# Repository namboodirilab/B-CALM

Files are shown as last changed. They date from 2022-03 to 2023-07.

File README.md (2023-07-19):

# Behavior Controller for Associative Learning and Memory (B-CALM): Software and Hardware Introduction 
This readme file briefly introduces the supplementary files for the Behavior controller system for assoctiative learning and memory (B-CALM). You can access the paper for free [here](https://rdcu.be/dha7x) <br />
 <br />

### [CIRCUIT SCHEMATIC PDF FILE](https://github.com/namboodirilab/B-CALM/blob/main/circuit%20schematic.pdf)
- This file contains the circuit schematic, building instructions and parts purchase list for our electronic system used in B-CALM.  <br />

### [TASK RUNNING OVERVIEW PDF FILE](https://github.com/namboodirilab/B-CALM/blob/main/Task%20running%20overview.pdf)
- This file contains the **MATLAB code and GUI setup instructions**, **task running instructions**, **the graphical user interface (GUI) parameters full explanation**, and **possible future tasks and parameter setting explanation**.   <br />

### [TASK CODES FOLDER](https://github.com/namboodirilab/B-CALM/tree/main/task%20codes)
 The first part of this folder contains the **MATLAB GUI code**--[headfix_GUI.m](https://github.com/namboodirilab/B-CALM/blob/main/task%20codes/headfix_GUI.m), **the actual GUI figure file made in GUIDE**--[headfix_GUI.fig](https://github.com/namboodirilab/B-CALM/blob/main/task%20codes/headfix_GUI.fig),  and **the data saving and plotting file** for current experiment--[conditioning_prog.m](https://github.com/namboodirilab/B-CALM/blob/main/task%20codes/conditioning_prog.m).
  
  We have also developed a programmatic GUI, running code with the plotting function in the [programmatic GUI folder](https://github.com/namboodirilab/B-CALM/tree/main/task%20codes/programmatic%20GUI) to adapt to MATLAB's future versions which will discontinue GUIDE. 

  The second part of this folder contains five Arduino task scripts for running five different experiments. Task parameters and instructions of running each one are documented in the [Task running overview](https://github.com/namboodirilab/B-CALM/blob/main/Task%20running%20overview.pdf). <br />
  - [Namlab_behavior_cues.ino](https://github.com/namboodirilab/B-CALM/tree/main/task%20codes/Namlab_behavior_cues) - This is experiment mode one in the GUI setting. This is for cue triggered experiments (both Pavlovian and cue-action-reward). <br />
  - [Namlab_behavior_randomrewards.ino](https://github.com/namboodirilab/B-CALM/tree/main/task%20codes/Namlab_behavior_randomrewards) - This is experiment mode two in the GUI, for lick training animals with a poission distribution of rewards. <br />
  - [Namlab_behavior_lickforreward.ino](https://github.com/namboodirilab/B-CALM/tree/main/task%20codes/Namlab_behavior_lickforreward) - This is experiment mode three in the GUI, for operant/instrumental action-reward associated tasks. <br />
  - [Namlab_behavior_decisionmaking.ino](https://github.com/namboodirilab/B-CALM/tree/main/task%20codes/Namlab_behavior_decisionmaking) - This is experiment mode four in the GUI, mainly for decision making tasks with the possible implentation of different cues, reward magnitudes, and delays for either choices. <br />
  - [Namlab_behavior_ramptiming.ino](https://github.com/namboodirilab/B-CALM/tree/main/task%20codes/Namlab_behavior_ramptiming) - This is experiment mode six in the GUI, for studying a ramp timing task with reward magnitude varying based on the ramp (not part of the B-CALM paper). <br />
  
  (These five experiments include nearly all possible task combinations and setups for running common associative learning and memory tasks. Other experiment mode task files beyond the scope of the paper are not included here currently since they are being validated. <br />
  
### [DATA ANALYSIS CODES FOLDER](https://github.com/namboodirilab/B-CALM/tree/main/data%20analysis%20codes)  <br />
  This folder contains five MATLAB data analysis codes for analyzing the five different tasks we've demonstrated in the paper. All analysis codes are documented to guide users to understand the logic behind our analysis. 
  - [cueactionrewardtask.m](https://github.com/namboodirilab/B-CALM/blob/main/data%20analysis%20codes/cueactionrewardtask.m) - This file is for analyzing and plotting the Cue-action-reward task in the paper. <br />
  - [desisionmakingtask.m](https://github.com/namboodirilab/B-CALM/blob/main/data%20analysis%20codes/decisionmakingtask.m) - This file is for analyzing the decision-making task in the paper. <br />
  - [operanttask.m](https://github.com/namboodirilab/B-CALM/blob/main/data%20analysis%20codes/operanttask.m) This is for analyzing the operant conditioning task demonstrated in the paper. <br />
  - [pavloviantask.m](https://github.com/namboodirilab/B-CALM/blob/main/data%20analysis%20codes/pavloviantask.m) - This file is for analyzing the Pavlovian conditioning file shown in the paper. <br />
  - [timingtask.m](https://github.com/namboodirilab/B-CALM/blob/main/data%20analysis%20codes/timingtaskraster.m) - This file is for analyzing the interval timing task demonstrated in the paper. <br />
  
### [HEAD_FIXED_SETUP FOLDER](https://github.com/namboodirilab/B-CALM/tree/main/head_fixed_setup)  <br />
  This folder contains:
  - [head_fixed stage setup overview](https://github.com/namboodirilab/B-CALM/blob/main/head_fixed_setup/Head-fixed%20stage%20setup%20overview.pdf) - this file explains the instructions for building our current head_fixed stage and the reward delivery system. It also contains the overview pictures for our 3D printing parts, lick tube positioning instructions and the head-fixed stage parts purchase information index.
  - [CAD files folder](https://github.com/namboodirilab/B-CALM/tree/main/head_fixed_setup/CAD%20files) - this folder contains the [head-fixed stage base design](https://github.com/namboodirilab/B-CALM/blob/main/head_fixed_setup/CAD%20files/base%20design%20clean.step), the [head-fixed holder top piece](https://github.com/namboodirilab/B-CALM/blob/main/head_fixed_setup/CAD%20files/Original_holdertop.SLDPRT), and the [head-fixed holder bottom piece](https://github.com/namboodirilab/B-CALM/blob/main/head_fixed_setup/CAD%20files/Original_holderbottom_mod.SLDPRT). All three items were custom made through [eMachineShop](https://www.emachineshop.com/main/). (Orders require submiting quotes with those CAD files through the eMachineShop website. Please note that this is not to endorse eMachineShop. Any machine shop should be able to make these parts)
  - [3D printing files](https://github.com/namboodirilab/B-CALM/tree/main/head_fixed_setup/3D%20printing%20files) - this folder contains all the 3D printing files we utilized in the head-fixed stage setup.
    - [Final_2_lick_tube_holder_levelholes.stl](https://github.com/namboodirilab/B-CALM/blob/main/head_fixed_setup/3D%20printing%20files/Final_2_lick_tube_holder_levelholes.stl) - this is the middle two lick tube holder piece.
    - [Final_retraction_solenoid_wing_holder.stl](https://github.com/namboodirilab/B-CALM/blob/main/head_fixed_setup/3D%20printing%20files/Final_retraction_solenoid_wing_holder.stl) - this is the two retraction solenoid wing holder.
    - [Final_left_retraction_solenoid_attachment.stl](https://github.com/namboodirilab/B-CALM/blob/main/head_fixed_setup/3D%20printing%20files/Final_left_retraction_solenoid_attachment.stl) - this is the left side retraction solenoid attachment piece. Left is relative to the mouse snout. 
    - [Final_right_retraction_solenoid_attachment_30mm.stl](https://github.com/namboodirilab/B-CALM/blob/main/head_fixed_setup/3D%20printing%20files/Final_right_retraction_solenoid_attachment_30mm.stl) - this is the right side retraction solenoid attachment piece.

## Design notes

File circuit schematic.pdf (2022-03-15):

Circuit Schematic, building instructions, and parts list

Here, we show the circuit schematic. We first discuss why we chose to use breadboards as our permanent circuits instead of printed circuit boards (PCBs) before explaining how to wire the circuit and how the circuit operates.

PCB vs breadboards:

Our primary design goal for the circuit was for it to be stable, yet flexible enough that hardware components can be easily added, removed, or replaced. For this reason, we decided to build a permanent solution using breadboards. The choice of breadboards for a permanent circuit may be non-intuitive. Hence, we explain this choice here.

1. PCBs are fantastic when a circuit is fully stable and no change in hardware configuration will be necessary in the future. However, when the hardware configuration changes, a PCB needs to be redesigned, which requires time, effort, and money. Since we would like the hardware in our system to be quickly modifiable, we resort to using breadboards, wherein changes are easy to make.
2. Though circuits on breadboards can be unstable when assembled with poor quality boards, or with inappropriate wires, they can be highly stable when made appropriately (good quality boards, solid core wires and leads with appropriate thickness).
3. When circuit components fail, they can be quickly replaced from a breadboard. This is much harder with fully assembled PCBs, especially those with built-in small form factor chips.
4. Making this circuit on a breadboard allows other labs to potentially modify the circuit to add their own hardware. A fully assembled PCB would not easily allow such modification.
5. Despite these advantages, breadboards have a major disadvantage due to stray capacitances. These capacitances slow signal processing and this is a major reason why breadboards are not used for applications requiring sub-microsecond clocking. However, for controlling animal behavior, the highest signal frequencies of interest are only over millisecond timescales. Thus, in this frequency space, breadboards are fully functional. Indeed, one can make a functional computer on breadboards despite the constraints on processing speed (https://eater.net/8bit/)

How this circuit works:

The general principle of design for this circuit is simple. For any hardware component, we allocate one of the IO pins on the Arduino Mega as an input or an output. Since in our case, all such connections are digital, we use the digital pins of the Arduino Mega. In our case, the inputs are lick measurements for the three lick tubes (left, right and center). The outputs are one to four fluid delivery solenoids, two lick tube retraction solenoids, two buzzers, and two LEDs. The fluid delivery solenoids can be hooked up to the three lick tubes, with one each for the left and right tube and two for the two separate electrically connected tubes in the center lick tube. In practice, for most simple experiments, one would only need a single fluid delivery solenoid for one of the center tubes. In the behavioral tasks shown in Zhou et al., we use only one fluid delivery solenoid to deliver sucrose, except for the experiment in which quinine is also delivered (two total fluid delivery solenoids in this case). Each of these connection types (lick detection, buzzer, LED, fluid delivery solenoid, lick tube retraction solenoid) has its own circuit motif that is repeated for the desired number of hardware components. These are described below.

Lick detection: We used a previously published circuit for detecting licks (Slotnick 2009). The only two changes we made are to add a Schmitt trigger to debounce the detected licks, and to use a 9V power supply instead of a battery.

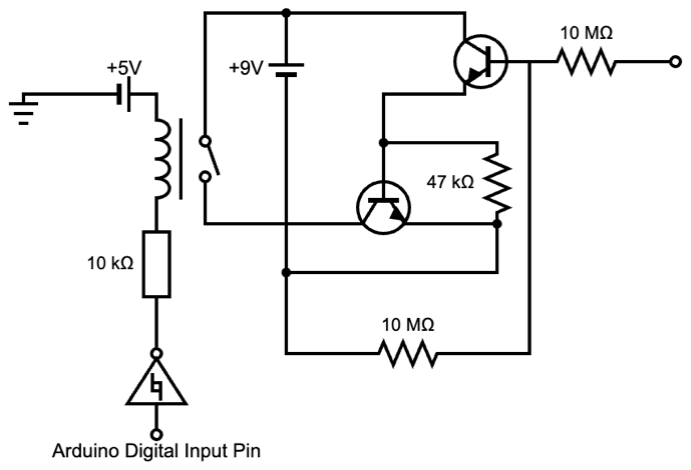
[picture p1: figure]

Buzzers and LEDs: This circuit simply connects one lead of the buzzer/LED to an Arduino digital output pin through a resistor, with the other lead connected to ground.

Fluid delivery solenoid: We used a power transistor (TIP120) as a switch to drive a 24V supply through the solenoid whenever the base of the transistor was turned to a high voltage by the Arduino output pin. Thus, the Arduino output pin was connected to the base of TIP120 through a resistor (to limit current) and the solenoid was connected on a path from a 24V supply to the collector of the TIP120. The emitter was connected to ground. In effect, this circuit operates as a switch, with the Arduino output either causing flow of current to the solenoid thereby turning it on, or preventing flow of current, thereby turning it off.

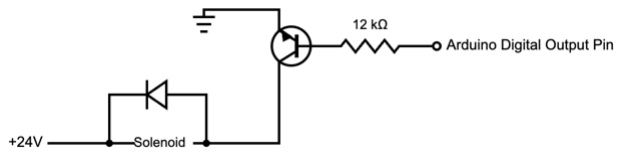
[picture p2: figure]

Lick tube retraction solenoid: This uses a similar circuit as the fluid delivery circuit, but with a MOSFET instead of TIP120. The MOSFET is more power efficient, thereby reducing any concerns of heating when the solenoid is turned on for longer durations. A MOSFET could also be used for the fluid delivery solenoid circuit.

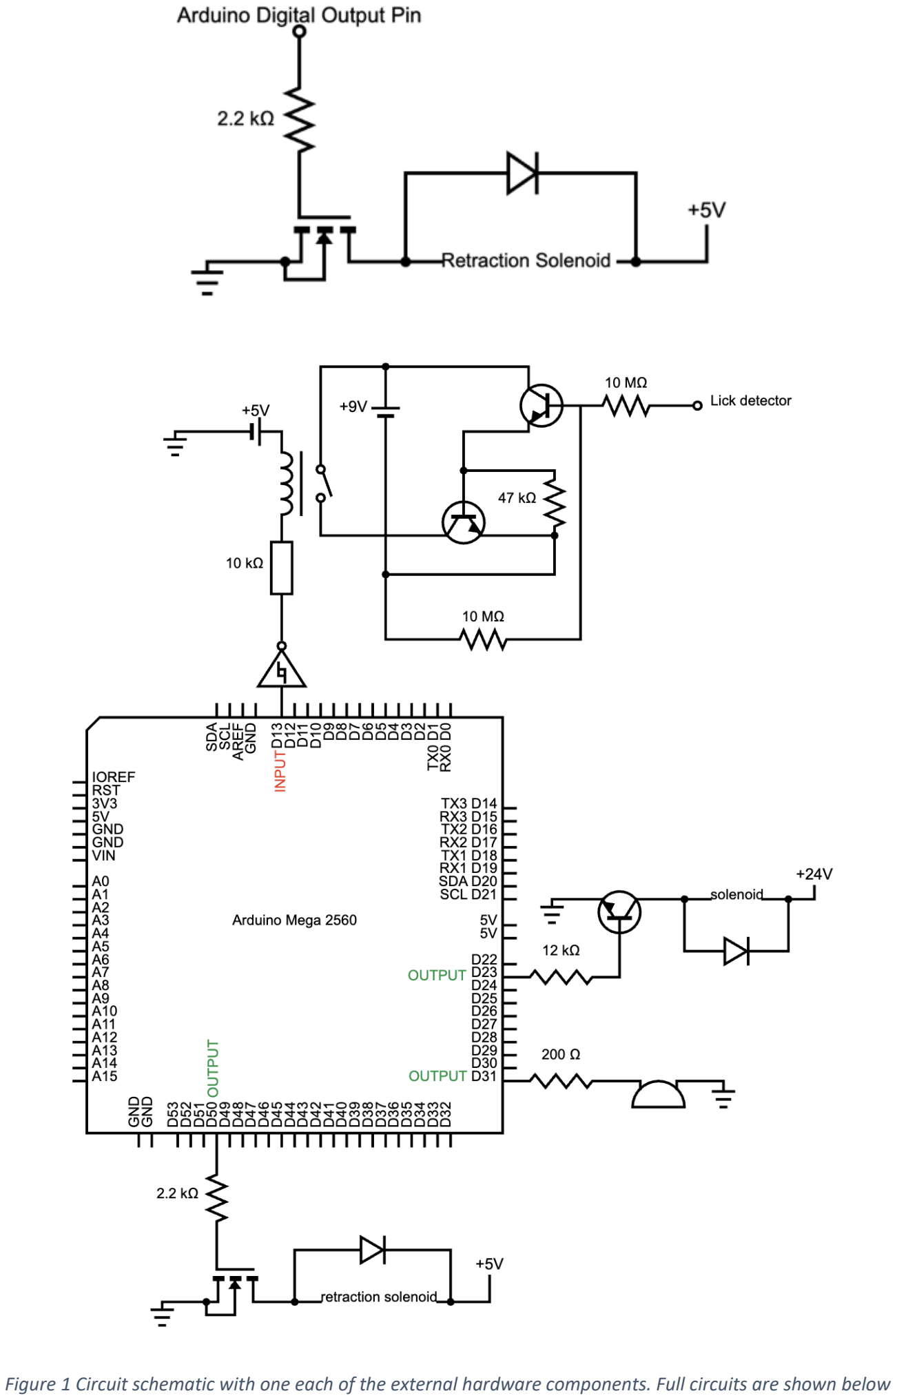
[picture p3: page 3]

Figure 1 Circuit schematic with one each of the external hardware components. Full circuits are shown below

Why we show a hand-drawn schematic (in addition to the electronically generated schematic):

Here, we show both an electronic schematic of the circuit (Fig 4) and our original hand-drawn design (Fig 2) that was used to conceptualize the circuit. The electronic circuit was designed using PICAXE Electronic Bread Board Layout Emulator (PEBBLE). We show the hand-drawn design since in personal communication with others, we have found that it provides a lower barrier to entry to understand the circuit and to make modifications. The electronic schematic provides the exact breadboard locations in which we wire our circuit and thus, can be mimicked without any understanding of the circuit function.

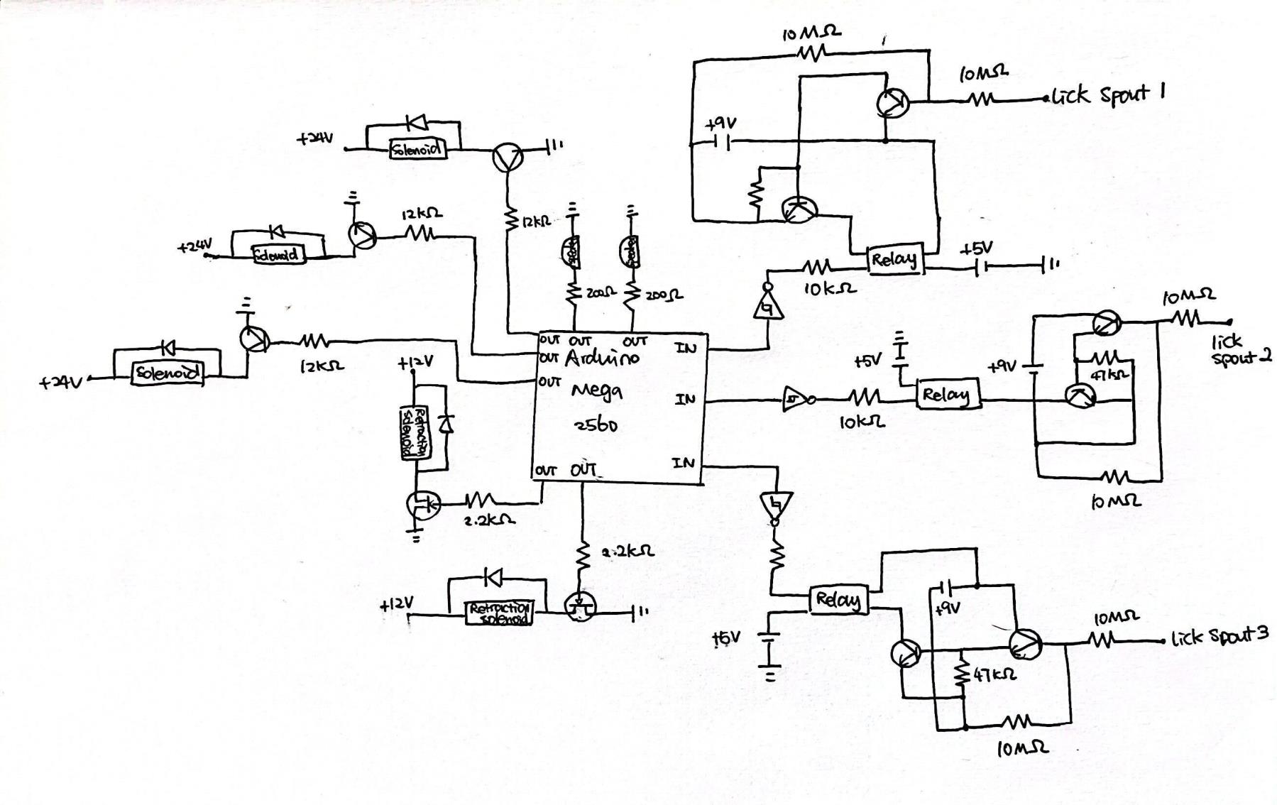
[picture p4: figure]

Figure 2 Hand-drawn full circuit schematic

Parallel running:

Our system can support multiple Arduino boards and behavioral box setups using a single computer. Separate behavioral setups are connected to the computer via USB connection. Each separate MATLAB window can control one setup and multiple setups can be executed simultaneously.

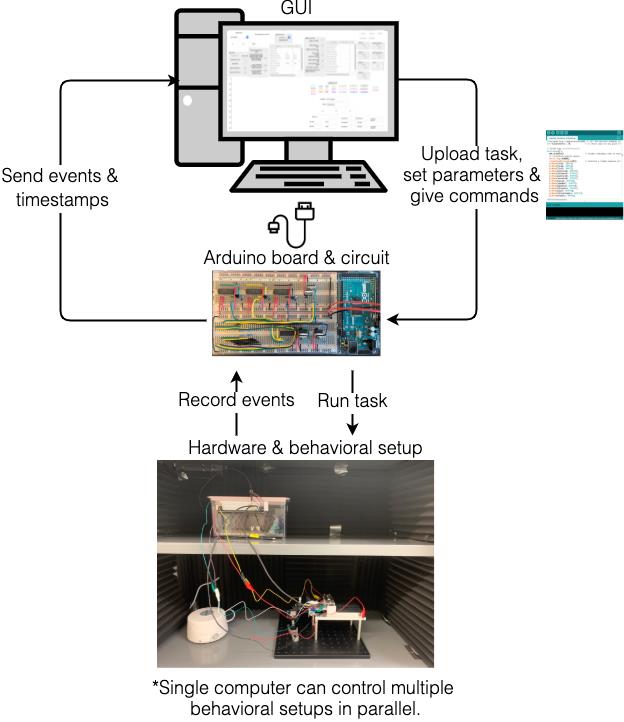
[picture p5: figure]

Building Instructions:

1. Please refer to the following photos attached for the complete circuit. All parts needed to complete the circuit is listed here. Please follow the same schematic for circuit layout.

Parts needed:

i. Lickometer systems: 10 MΩ resistors x 6, 47 kΩ resistors x 3, 10 kΩ resistors x 3, reed relay x 3, 2N222 transistor x 3, Schmitt trigger x 1, solid core wires
ii. | Linear actuator system: 2.2 kΩ resistors x 2, Power MOFSET x 2, solid core
| wires
iii. | Speakers & lights: 200 Ω resistors x 4 (speaker resistors vary, please use the
| resistor kit to test the best value)
iv. | Solenoids: 5.6 kΩ resistors x 4, TIP120 x 4, single diode x 4, solid core wire

Figure 3 System overview

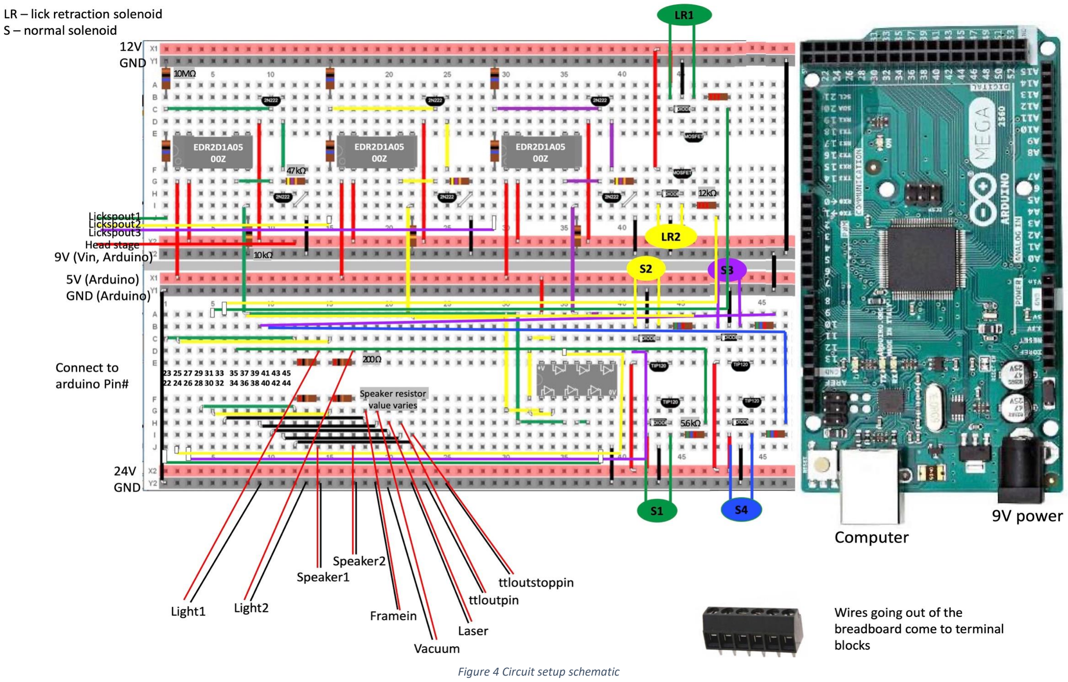
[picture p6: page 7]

Figure 4 Circuit setup schematic

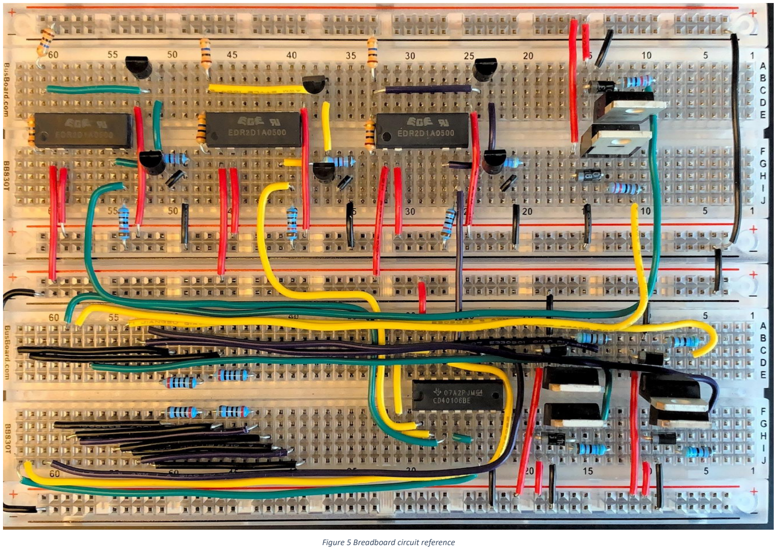
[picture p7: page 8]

Figure 5 Breadboard circuit reference

2. Dremel one rectangular opening of 15 x 0.6 cm (150 x 6 mm) on one long side (horizontal), roughly 3 cm from the top edge of the box. Dremel two square openings with length of 16 mm and 11 mm at the right bottom corner of the plastic box (Amazon 14090MDT). The distance between the two squares is around 10 mm, the distance from the bottom edge of the box to the bottom side of the squares is also around 10 mm, and the distance from the right side of the box to the right square is roughly 1.5cm. The two square openings are for putting the USB cord and 9V power to the Arduino board.

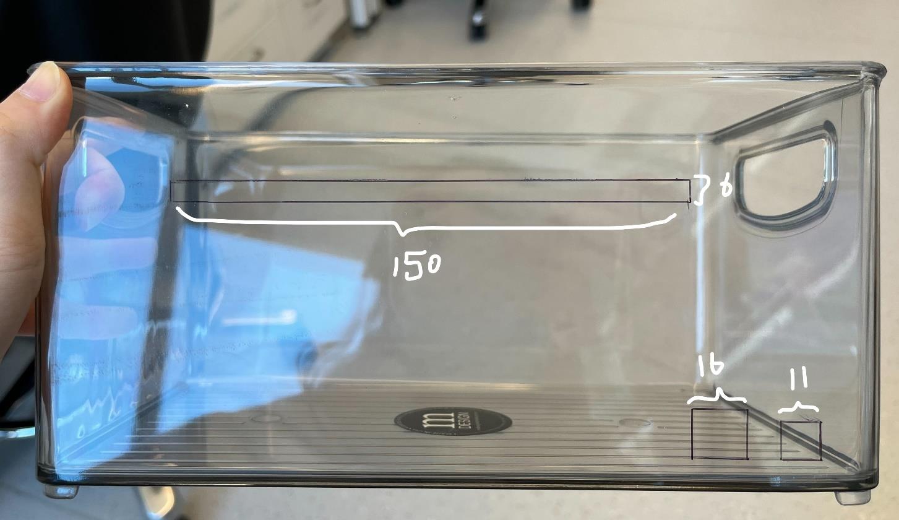
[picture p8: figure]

Figure 6 Plastic box openings size

3. Use super glue to glue 7 terminal blocks (Molex 0393570006) together. Make sure the opening slots are all facing the same way.

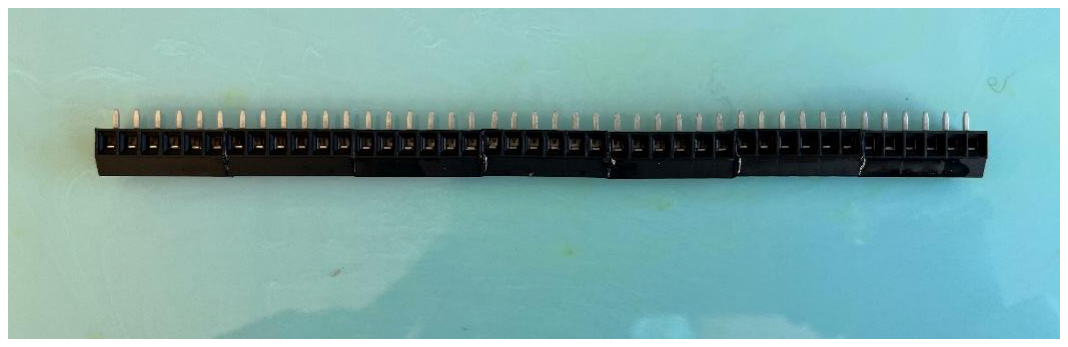
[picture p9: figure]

Figure 7 Glued terminal block

4. Place the glued terminal block into the plastic box opening with the screw slots side facing upwards. Use a hot glue gun to glue the bottom of the terminal block body onto

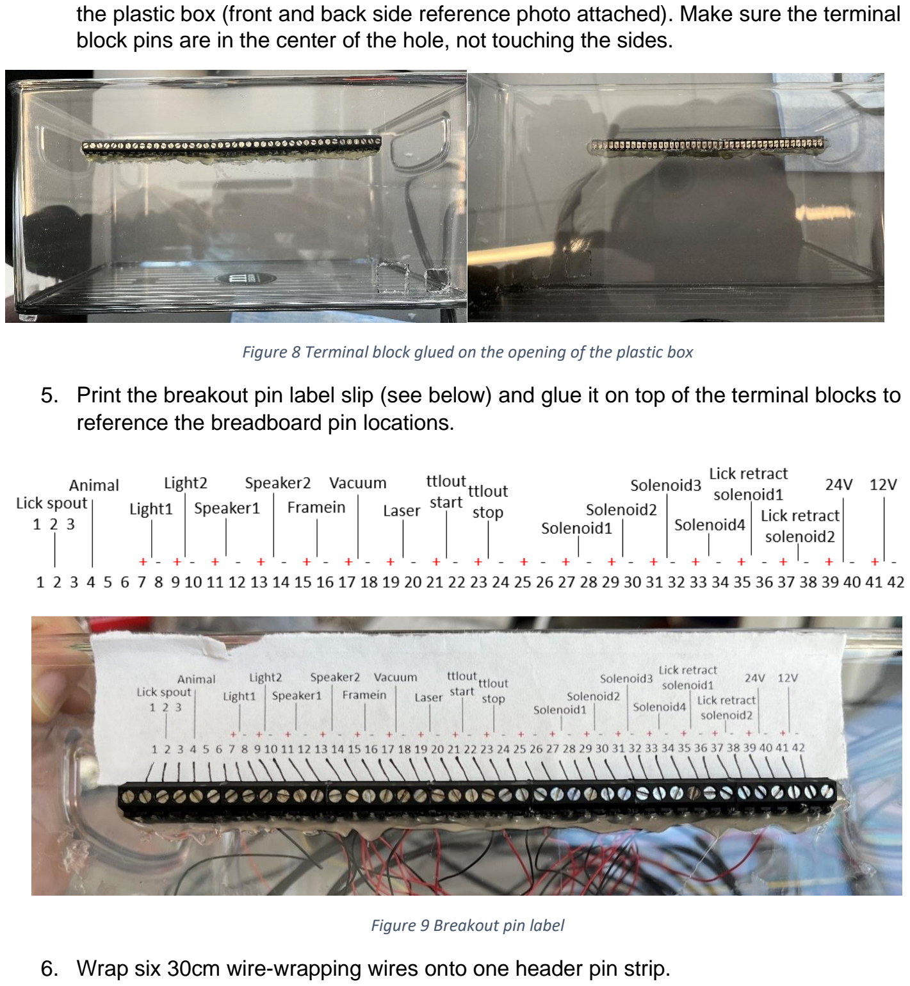
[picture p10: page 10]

the plastic box (front and back side reference photo attached). Make sure the terminal block pins are in the center of the hole, not touching the sides.

Figure 8 Terminal block glued on the opening of the plastic box

5. Print the breakout pin label slip (see below) and glue it on top of the terminal blocks to reference the breadboard pin locations.

Figure 9 Breakout pin label

6. Wrap six 30cm wire-wrapping wires onto one header pin strip.

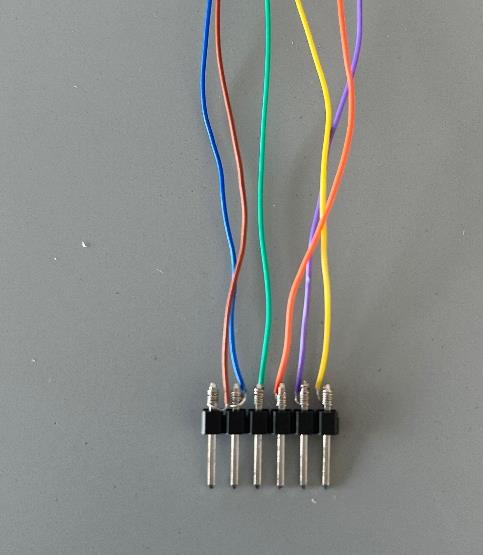
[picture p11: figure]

Figure 10 Wire wrapping on header pin strip

7. Add a heating shrink tubing to the six wires to secure them together. Leave some space on the other end to wrap the other end on another header pin strip. Make sure the order of the wires is the same for the two header pin strips (in this example: yellow→purple→orange→green→blue→brown). (This is inspired from https://hackaday.com/2019/01/06/making-your-breadboard-projects-a-little-morepermanent/).

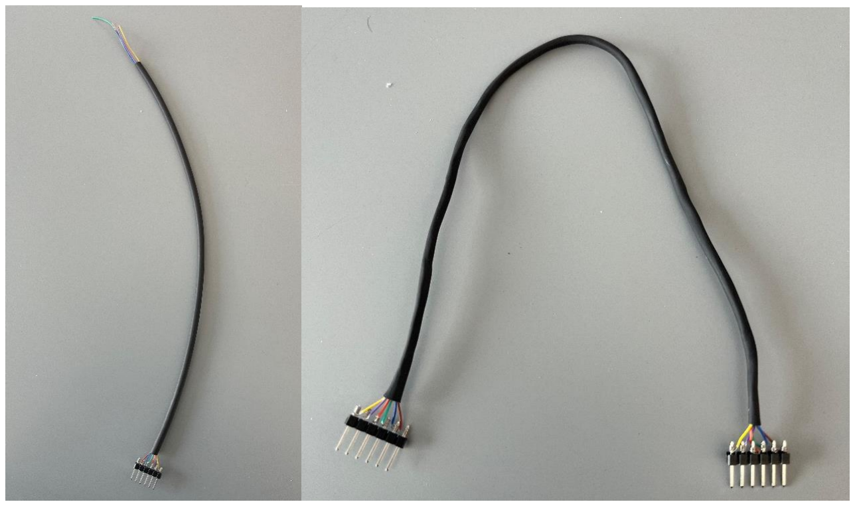
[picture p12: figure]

Figure 11 Make wire strip with two header pin strips

8. Use a hot glue gun to add a protective layer over the header pin strips. Repeat four times to make four wire strips total.

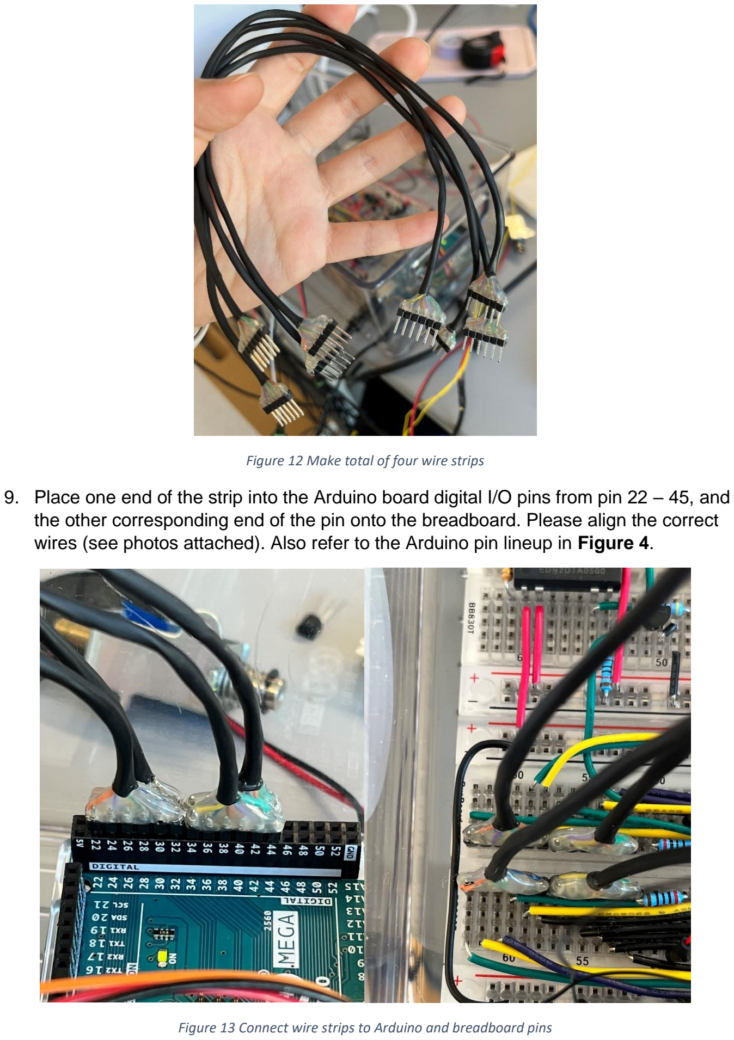
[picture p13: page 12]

Figure 12 Make total of four wire strips

9. Place one end of the strip into the Arduino board digital I/O pins from pin 22 – 45, and the other corresponding end of the pin onto the breadboard. Please align the correct wires (see photos attached). Also refer to the Arduino pin lineup in Figure 4.

Figure 13 Connect wire strips to Arduino and breadboard pins

10. Connect the 5V pin, ground pin, and Vin pin on the Arduino board to 5V, ground, and 9V respectively on the breadboard using 10 cm jumper wires.

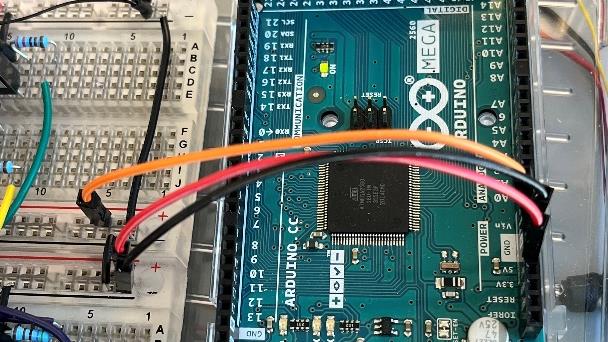
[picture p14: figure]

Figure 14 Connect Arduino 5V and ground to correct place on breadboard

11. Wrap one side of wire-wrapping wires onto the terminal block and the other side to a solid core wire to connect the circuit board to the terminal blocks. Location of the wires are indicated on Figure 4.

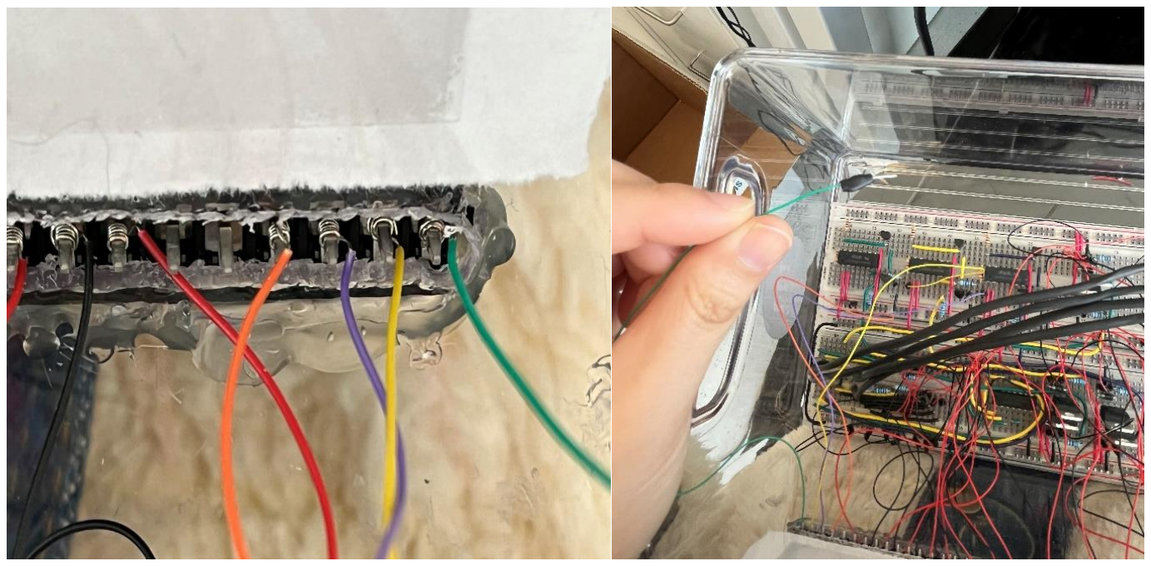
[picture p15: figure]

Figure 15 Use wire-wrapping wire to connect the terminal block pin and appropriate location on the breadboard

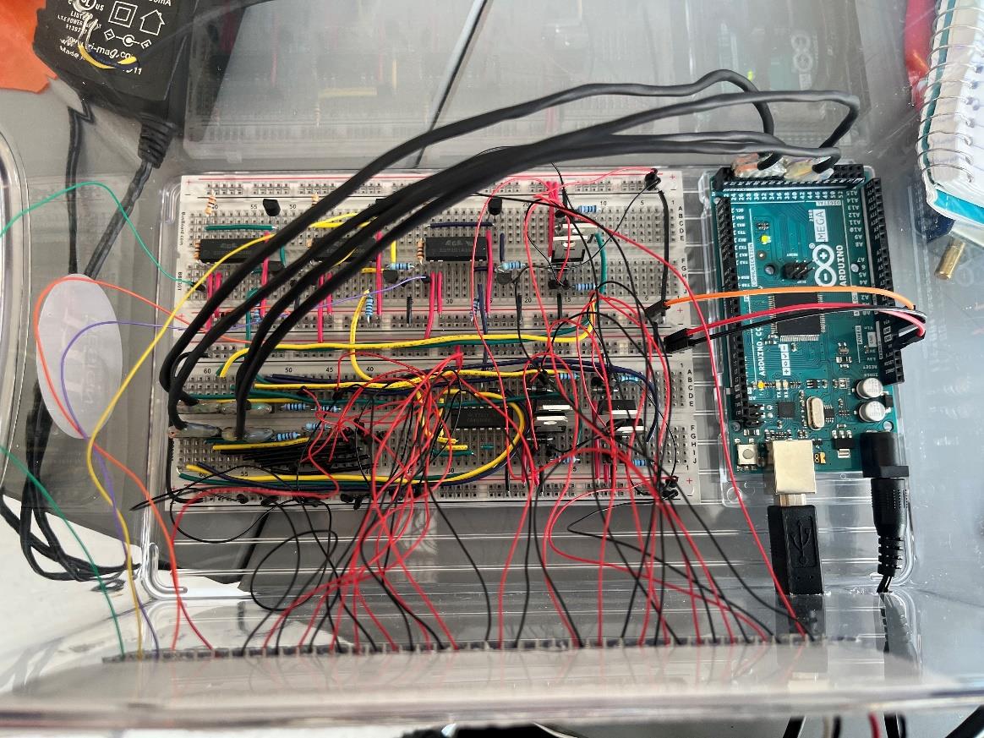
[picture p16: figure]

Figure 16 Wire-wrapping to connect terminal blocks and the breadboard pins

12. Use jumper wires and a female DC power adapter to connect the 12V power adapter and 24V power adapter to the corresponding breakout pins.

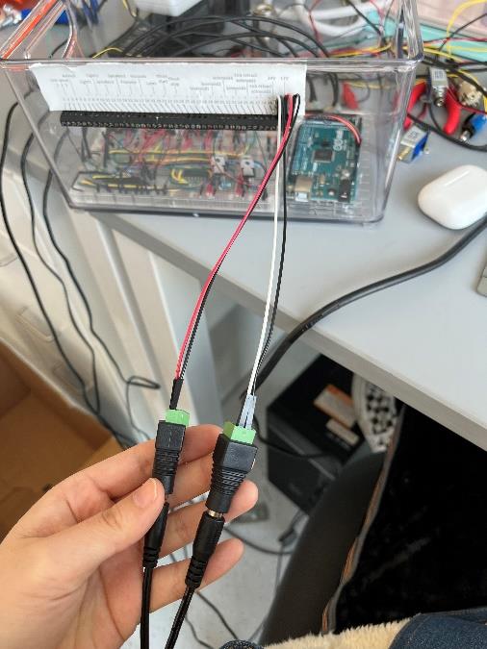
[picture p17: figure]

Figure 17 Use female DC power adapter to connect 12V and 24V power to the breakout pins

13. Connect a 9V power adapter to the Arduino board and use a USB A-B 2.0 cable to connect the Arduino board and computer. Both wires go through the opening holes at

the right bottom corner.

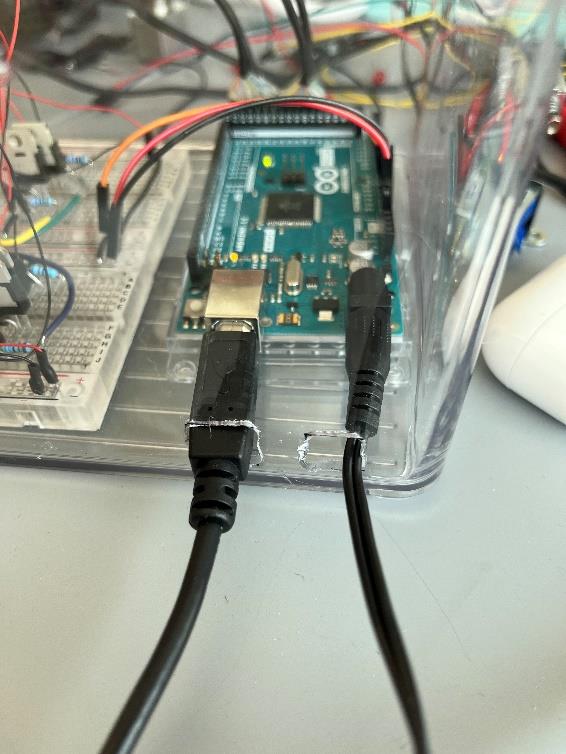
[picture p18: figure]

Figure 18 Connect the Arduino via USB port to the computer and power up with a 9V power adapter.

14. Solder hardware components (speakers, solenoids, linear actuators, lights etc) to desired lengths and connect them to the correct breakout pins from the outside of the box.

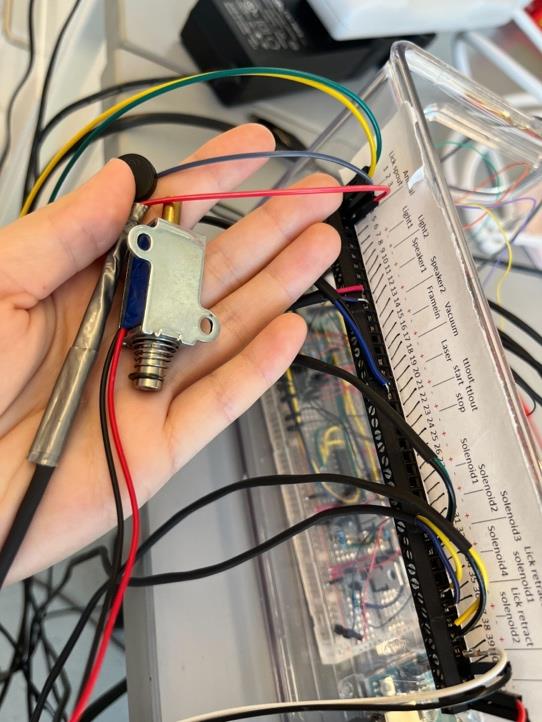
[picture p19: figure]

Figure 19 Connect soldered hardware to corresponding breakout pins on terminal blocks

# Appendix

## Circuit Parts Purchase Information

Item Name | Function | Vendor/ manufacturer part # | Quantity per system | Unit Cost ($) | Link
Arduino Mega 2560 board | Runs Arduino program: triggers solenoids and speaker output and receives input from lickometer | Arduino A000067 | 1 | 40.3 | https://www.digikey.com/en/products/detail/arduino/A000067/2639006? (https://www.digikey.com/en/products/detail/arduino/A000067/2639006) s=N4IgjCBcoLQBxVAYygMwIYBsDOBTANCAPZQDa4ADAKwUgC 6A vg4QExkgCCF3FAbAOz0GQA
Circuit breadboard | Base for wiring components | BB1660T | 1 | 15 | https://www.mouser.com/ProductDetail/BusBoard-Prototype-Systems/BB1660T?qs=I13xAFqYpRQG%252BRiHwK91ww%3D%3 D
Solenoid | Facilitates fluid delivery and vacuum function | Parker 003-0257-900 | 4 | 108 | https://ph.parker.com/us/12051/en/series-3-miniature-inert-liquid-valve/003-0257-900
5.6 kΩ resistor | Delivers proper current to solenoid | MBB02070C560 1FCT00 | 4 (1 per solenoid) | 0.27 | https://www.digikey.com/en/products/detail/vishay-beyschlag-draloric-bc-components/MBB02070C5601FCT00/5063492
TIP120 | Power transistor for switching on reward solenoid with Arduino | STMicroelectron ics TIP120 | 4 (1 per solenoid) | 0.75 | https://www.digikey.com/en/products/detail/stmicroelectronics/TIP120/603564
Single diode | Prevent current backflow | 1N4001DITR-ND | 4 (1 per solenoid) | 0.22 | https://www.digikey.com/en/products/detail/diodes-incorporated/1N4001-T/45351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 sypOi250ikLwQE3NXUGtQWzKWpEppk4gC_jrw0GRoCU7gQAvD_ BwE
10 MΩ resistor | Delivers proper current to first transistor in lickometer | YAGEO CFR-25JB-52-10M | 6 (2 per lickometer ) | 0.1 | https://www.digikey.com/en/products/detail/yageo/CFR-25JB-52-10M/36371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 dib (https://www.digikey.com/en/products/detail/yageo/CFR-25JB-52-10M/36371) Tbmy5abxGTwf8neFq2baKoy5_R3eO4NPBAdzBoC4tIQAvD_BwE
47 kΩ resistor | Delivers proper current to second transistor in lickometer | Vishay Beyschlag/Dralo ric/BC Components MBB02070C470 2FCT00 | 3 (1 per lickometer ) | 0.27 | https://www.digikey.com/en/products/detail/vishay-beyschlag-draloric-bc-components/MBB02070C4702FCT00/5063436
10 kΩ resistor | Delivers proper current to reed relay in lickometer | Vishay Beyschlag/Dralo ric/BC Components MBB02070C100 2FRP00 | 3 (1 per lickometer ) | 0.03 | https://www.digikey.com/en/products/detail/vishay-beyschlag-draloric-bc-components/MBB02070C1002FRP00/338172 (https://www.digikey.com/en/products/detail/vishay-beyschlag-draloric-bc-components/MBB02070C1002FRP00/338172)
Reed relay | Use to relay licks from lickometer to Schmitt | Excel Cell Electronics (https://www.jameco.com/shop/KeywordSearchResultView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) EDR2D1A0500Z | 3 (1 per lickometer ) | 3.19 | https://www.jameco.com/z/EDR2D1A0500Z-Excel-Cell-Electronics-Reed-Relays-SPST-NO-0-5A-5VDC-500Ohm-Thru-Hole_138431.html

Solenoid
(4)

Lickometer
(3)

| | trigger for detection; gates solenoid opening
| 2N222 transistor | Gates relay of licks from lickometer | MCIGICM 3145241 | 3 (1 per lickometer ) | 0.035 | https://www.amazon.com/McIgIcM-2n2222-transistor-Through-2n2222a/dp/B06XPWS52G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
| Schmitt trigger | Acts as a noise filter to detect real licks | TEXAS INSTRUMENTS CD40106BE | 1 (1 per 3 lickometer ) | 0.933 | https://www.newark.com/texas-instruments/cd40106be/ic-hex-inverter-4000-cmos-14dip/dp/33AH3784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
Linear actuator (2) | Linear actuator | To make retractable lick tube | Adafruit 412 | 2 | 7.5 | https://www.adafruit.com/product/412
| 2.2 kΩ resistor | Delivers proper current to linear actuator | Vishay Beyschlag/Dralo ric/BC Components MBB02070C220 1FCT00 | 2 (1 per actuator) | 0.26 | https://punchout.digikey.com/product-detail/en/MBB02070C2201FCT00/BC3668CT-ND/7351098/?itemSeq=343301088
| Power MOFSET | Power transistor for switching on linear actuator | Adafruit 355 | 2 (1 per actuator) | 1.75 | https://www.adafruit.com/product/355
Speaker (2) | Resistor kit | Kit for common resistor values, mostly used for delivering proper current to speakers | E-Projects A-0005-A02 | 1 | 16.66 | https://www.amazon.com/Projects-EPC-102-Value-Resistor-Kit/dp/B00E3JGGF2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
| Large enclosed piezo w/Wires | Large speaker for lower frequency cues | Adadruit 1739 | 1 | 0.95 | https://www.adafruit.com/product/1739?gclid=Cj0KCQjwzbv7BRDIA RIsAM-A6-2am1kPGUa6JCXs49LjeeilICKSZSlu-3cUP1_4B_kfmQVM9SapoPoaAgJXEALw_wcB
| Small enclosed piezo w/Wires | Small speaker for higher frequency cues | Adadruit 1740 | 1 | 0.95 | https://www.adafruit.com/product/1740#description
Light (2) | 200 Ω resistor | Delivers proper current to lights | From the above resistor kit | 2 | NA | https://www.amazon.com/Projects-EPC-102-Value-Resistor-Kit/dp/B00E3JGGF2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
| Pre Wired-LED Diodes Light 5mm-Blue | LED light for visual cue | ToToT PWDIODE-30-Blue | 2 | 0.253 | https://www.amazon.com/gp/product/B07QFQ24X2/ref=ppx_yo_dt_b_search_asin_title?ie=UTF8&psc=1
Power Supply | 24V/2A Power adapter | Delivers power to solenoids | Tri-Mag, LLC L6R48-240 | 1 | 19.11 | https://www.digikey.com/en/products/detail/tri-mag-llc/L6R48-240/7682649?s=N4IgTCBcDaIDIDYBKAWAHAWjCgDCAugL5A
| 12V/2A power adapter | Delivers power to linear actuator | Tri-Mag, LLC L6R24-120 | 1 | 9.74 | https://www.digikey.com/en/products/detail/tri-mag-llc/L6R24-120/7682639

| 9V/1A power adapter | Powers Arduino board and delivers power to lick detector circuit | Tri-Mag, LLC L6R12H-090 | 1 | 7.62 | https://www.digikey.com/en/products/detail/tri-mag-llc/L6R12H-090/7682626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
| Female DC power adapter | Connects power supply to breadboard when soldered to wires | Adafruit 368 | 2 | 2.00 | https://www.adafruit.com/product/368?gclid=CjwKCAjwh7H7BRBBEi wAPXjadvcNzmKGxGIewd8k9frrNSDPrIrKjcvOrcuOantF2J9L8xBGz 5jd7BoCJYoQAvD_BwE
| USB A-B 2.0 Cable | Connects computer w/USB-A port to Arduino board | Qualtek 3021001-03 | 1 | 2.63 | https://www.digikey.com/en/products/detail/qualtek/3021001-03/1531288?s=N4IgTCBcDaIIoGYBsBGAtAOQCIgLoF8g
| Solid-core wire spool | Connects wires for breadboard | Adafruit 290 | 5 colors x 25 ft (Black, Red, Green, Yellow, Purple) | 2.95 | https://www.adafruit.com/product/290
| Wire-Wrapping 30AWG wires | Connects circuit breadboard to terminal block | CECOMINOD03 5080 | 1 | 10.99 | https://www.amazon.com/URBEST-Solder-Coated-Wire-Wrapping-Celsius/dp/B01LWI20M0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
| Jumper wire kit (M to M) | Connect circuit elements and solder to elements to connect to board (10 cm, 15 cm, 30 cm) | EDGELEC ED-DP_L15_M-M_120pcs | 1 set per length (120pcs) | 7.49 | https://www.amazon.com/EDGELEC-Breadboard-Optional-Assorted-Multicolored/dp/B07GD431C1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
| Screw terminal block | Connect breadboard wires to external connections, mount directly on a plastic enclosure | Molex 0393570006 | 7 | 1.86 | https://www.digikey.com/en/products/detail/molex/0393570006/1280 713
| Header pin strip | Provides a wrapped wire connection to breadboard from Arduino | Harwin (https://www.mouser.com/manufacturer/harwin/) M20-9990646 | 8 | 0.165 | mouser.com/ProductDetail/Harwin/M20-9990646?qs=Jph8NoUxIfXDcWZbabSSiw%3D%3D
| Alligator clips | Connect to lick tubes and the animal base | MCIGICM test lead-10 | 4 | 0.499 | https://www.amazon.com/MCIGICM-10Pcs-Alligator-Clips-24AGW/dp/B07PHCK3VX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 &hvptwo=&hvadid=343252324310&hvpos=&hvnetw=g&hvrand=147 32595993421484942&hvqmt=&hvdev=c&hvdvcmdl=&hvlocint=&hvl ocphy=9061270&hvtargid=pla-759485340661
Enclosed Box for circuit setup | Plastic box | To place Arduino board and the breadboard | 14090MDT | 1 | 12.48 | https://www.amazon.com/dp/B085LQG3TR/ref=sbl_dpx_B00F4L6L30_0 (https://www.amazon.com/dp/B085LQG3TR/ref=sbl_dpx_B00F4L6L30_0)

Necessary
circuit
elements

Other
necessary
tools
Wire wrapping tool | Wrap wire onto header pin strip and terminal block | Electronix Express 0079947503340 7 | 1 | 23.99 | https://www.amazon.com/gp/product/B00BFYE0CY/ref=ppx_yo_dt_b_asin_title_o05_s00?ie=UTF8&psc=1
Wire stripper | Strip wires for breadboard connections | Adafruit 147 | 1 | 6.95 | https://www.adafruit.com/product/147
Hot glue gun | To apply hot glue and provide protective coating around flimsy electronic parts for mechanical stability | Aven Tools 17621 | 1 | 29.74 | https://www.digikey.com/en/products/detail/aven-tools/17621/7696004
Hot glue sticks | Glue for the glue gun | Aven Tools 17615 | 1 | 14.51 | https://www.digikey.com/en/products/detail/aven-tools/17615/7920431
Dremel | For cutting and polishing metal, plastic parts, etc | Dremel 4300-9/64 | 1 | 199.9 | https://www.digikey.com/en/products/detail/dremel/4300-9-64/9697074
Super glue | For gluing multiple terminal blocks together | Loctite 1699233 | 1 | 3.41 | https://www.amazon.com/gp/product/B01EZTPX94/ref=ppx_yo_dt_b_asin_title_o02_s00?ie=UTF8&psc=1
Soldering iron kit | For soldering and extending wires to desired length | Plusivo | 1 | 16.99 | https://www.amazon.com/Soldering-Iron-Kit-Temperature-Desoldering/dp/B07S61WT16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
Multimeter | For measuring voltage for circuit | Triplett 2030 | 1 | 31.79 | https://www.digikey.com/en/products/detail/triplett-test-equipment-and-tools/2030/11623185
Heat shrink tubing – 1/8 in | Covers soldered connections and indicates negative current wires | Electriduct HS3-0125-100-RD; HS3-0125-100-BK | 2 colors, red and black | 15.8 | https://www.amazon.com/Heat-Shrink-Tubing-1-100FT-Black/dp/B00FL4JO7U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 (https://www.amazon.com/Heat-Shrink-Tubing-1-100FT-Black/dp/B00FL4JO7U?s=gateway)
Heat gun | Use for heat shrinking | Apex Tool Group Mfr. 6966C | 1 | 173 | https://www.alliedelec.com/product/apex-tool-group-mfr-/6966c/71077034/
Screw-driver set mini | For screwing terminal block and connecting hardware elements | Rosewill RPCT-10001 | 1 | 19.99 | https://www.newegg.com/rosewill-rpct-10001/p/N82E16899261024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

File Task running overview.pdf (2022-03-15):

MATLAB code/GUI setup & task running overview:

1. Please download MATLAB (version 2021b for consistency) and Arduino IDE.
2. Open the headfix_GUI.m file in MATLAB and change the file main path in line 70 -72 to desired folder saving path-one example path shown here. Please make sure to include a subfolder named “data” in the main folder. This is where all the data will be saved.

Figure 1 Set main path and data saving subfolder in MATLAB code

3. Create an “uploads” folder under the main folder and update the Arduino hex file upload locations in the “uploadButton_Callback” function (currently in lines 303-317).

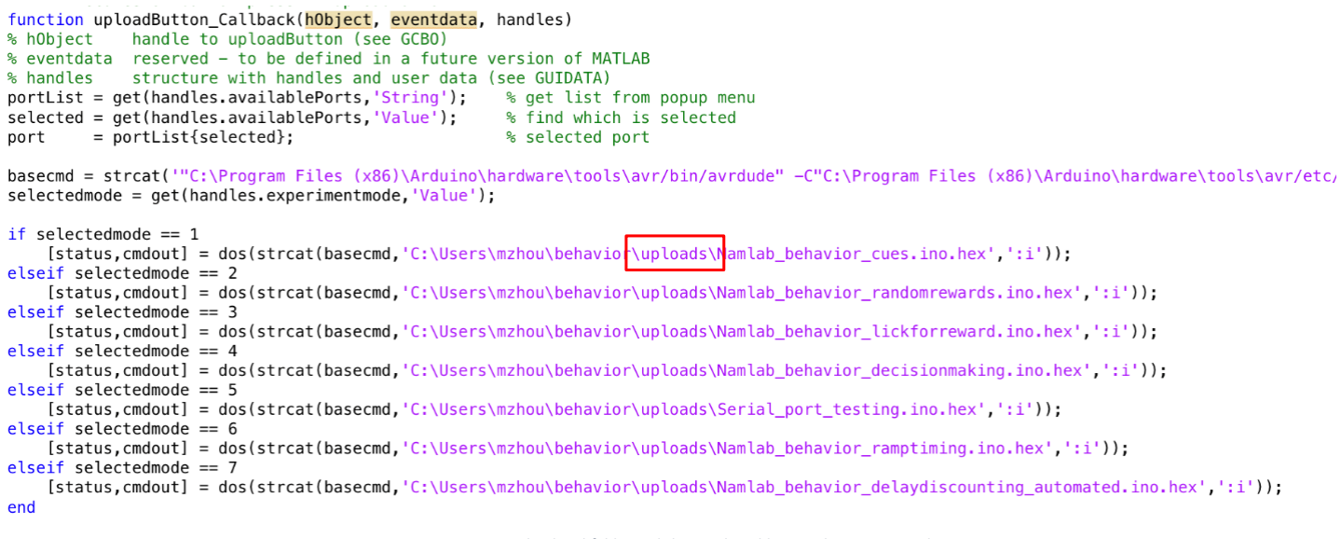
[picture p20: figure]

Figure 2 Create uploads subfolder and change the address in the MATLAB code

4. Open each Arduino task script .ino file in Arduino IDE. Open “Preferences” under the “File” menu bar and select “Show verbose output during upload”.

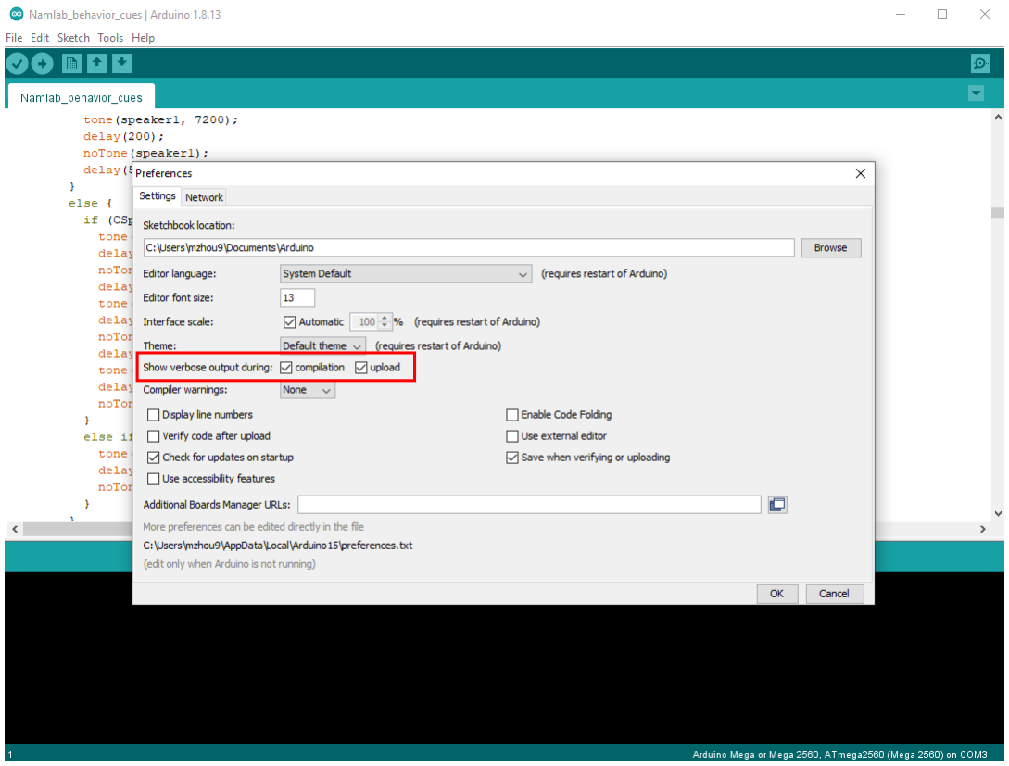
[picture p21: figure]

Figure 3 Preference window

5. Under the “Tools” menu bar, select board for Arduino mega 2560 board and select a vacant Arduino board in port. Hit the upload button to upload this file. Note down the uploaded file path. There are many online websites explaining how to get this hex file location for a code. An example is here: https://www.instructables.com/HOW-TO-GET-HEX-FILE-FROM-ARDUINO-/ (https://www.instructables.com/HOW-TO-GET-HEX-FILE-FROM-ARDUINO-/)
6. Go to the uploaded folder path. Copy and paste the .hex file into the “uploads” folder created in Steps 2 and 3. (Repeat for all Arduino task scripts).

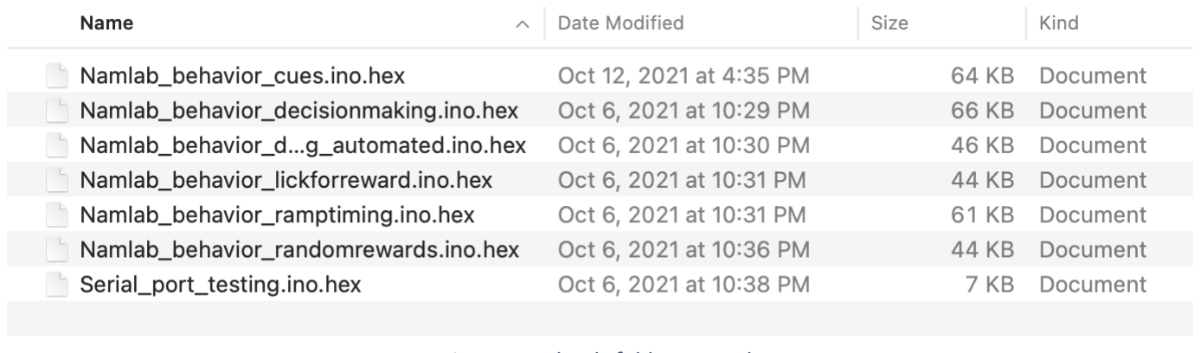
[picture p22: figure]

Figure 4 Uploads folder example

7. Make sure the conditioning_prog.m file is in the same folder as the headfix_GUI.m and headfix_GUI.fig files. This is for saving the experiment data and parameters and plotting real-time events during the experiment.

Task running instructions:

1. Open the headfix_GUI.m and hit “Run” function under the “Editor” menu.
2. Select available COM ports (corresponds to which Arduino board to connect to).

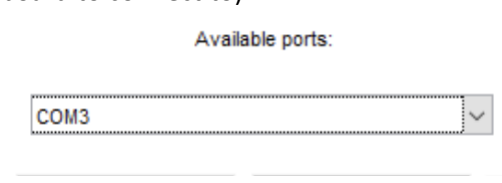
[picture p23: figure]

Figure 5 Choose an available Arduino port number

3. Select the experiment mode to run (1=run with cues, 2=only with random rewards given, 3=lick dependent rewards, 4=decision making task, 6=ramp timing task, 5=testing serial port connection) and press the “Upload to arduino” button to upload this selected experiment hex file to the selected Arduino board. If successful, the button text will display as “Successfully uploaded”. If unsuccessful, the button text displays “Unable to upload”; in that case, please check the file location and the corresponding code in the MATLAB code line 303-317.

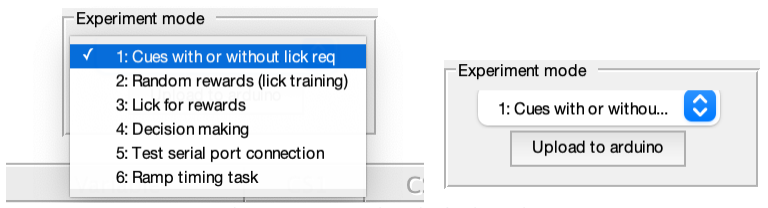
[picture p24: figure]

Figure 6 Select experiment mode and upload to Arduino

4. Hit “Link” to connect the computer and Arduino board with the serial port. Different sections of parameter editing will become active based on the experiment mode selected. (see GUI parameter full explanation section and possible task section below for how to set different parameters in different tasks).


Figure 7 Parameter setting section

5. After setting up all the parameters correctly, hit the “Send” button to send all parameters to the Arduino board.


Figure 8 Buttons for sending parameters to Arduino, starting experiment and stopping experiment

6. Test hardware components before starting the experiment if needed. For example, pressing “Test CS1”, “Solenoid 2 Manual”, “Lick retract solenoid 1 Manual” will turn on the hardware for a set length. Pressing the “Prime” button under any solenoid section will keep that particular solenoid open until the button is unclicked.


Figure 9 Testing hardware section

7. Start the experiment by hitting the “Start” button in Figure 7.
8. When the session ends, the experiment will stop automatically and be saved to the folder saving path (set during Step 2) as a .mat file with two variables: eventlog and params as a .mat file.
a. eventlog contains three columns: 1st column is all the event identifiers; 2nd column is time stamp of the event; 3rd column is identifier flag for either reward delivery status of the solenoid: 0=given, 1=missed, or for identifying the cue order: 0=first cue, 1=second cue).
b. params is a struct with all parameter names and values set for this experimental session for future reference.


Figure 10 Saved MATLAB file data preview containing two variables: eventlog and params

Graphical User Interface Sections | MATLAB saved parameter [# of items for this parameter]

Corresponding Arduino
parameter

Description of parameters


CS properties window | numtrials[4] | numtrials[0-3] | Number of trials for CS1-4
CSfreq[4] | CSfreq[0-3] | Sound frequencies for auditory cues (in kHz)
CSsolenoid[8] | CSsolenoid[0-7] | Designated two solenoids for each of the three cues 1-4:solenoid 1-4; 5/6: retraction solenoid 1/2; 56: retraction solenoid 1&2
CSprob[8] | CSprob[0-7] | Solenoid open probability
CSopentime[8] | CSopentime[0-7] | Solenoid open time
CSdur[8] | CSdur[0-3] | Cue durations
CS_t_fxd[8] | CS_t_fxd[0-7] | Fixed delay from cue to solenoids
CSpulse[4] | CSpulse[0-3] | Whether CS is a pulsed cue or not, 0=not pulsed, 1=pulsed
CSspeaker[4] | CSspeaker[0-3] | CS1-4 first cue speaker number
golickreq[4] | golickreq[0-3] | For cue-action-reward task, number of lick requirements met on selected tube to obtain the second solenoid for each cue
golicktube[4] | golicktube[0-3] | designated lick tube for cue-action-reward task
CSsignal[4] | CSsignal[0-3] | CS first cue signal type, 1=sound, 2=light
CSlight[4] | CSlight[0-3] | CS1-4 first cue light number
CSrampmaxdelay[4] † † see legend at the bottom of the table about parameters in brown text | CSrampmaxdelay[0-3] | ramp max delay for ramp timing task for CS1-4

# Graphical User Interface Parameters Explanation

CSrampexp[4] | CSrampexp[0-3] | ramp exponential factor for ramp timing task for CS1-4
CSincrease[4] | CSincrease[0-3] | Increasing or decreasing frequency for CS1-4
delayforsecondcue[4] | delayforsecondcue[0-3] | Time between first and second cue if there is second cue for each CS1; solenoids are delivered based on second cue onset
CSsecondcue[4] | CSsecondcue[0-3] | Check if there is a second cue for each CS, 1=sound, 2=light, 0=no second cue
CSsecondcuefreq[4] | CSsecondcuefreq[0-3] | Second cue frequency if it is a sound cue
CSsecondcuespeaker[4] | CSsecondcuespeaker[0-3] | Second cue speaker number
CSsecondcuelight[4] | CSsecondcuelight[0-3] | Second cue light number


| | for exponential trials
maxITI | maxITI | max ITI for exponential ITI trials, equals to truncation of ITI = min(maxITI, 3*meanITI)
minITI | minITI | minimum ITI for uniform distribution trials
expitiflag | intervaldistribution | exponential ITI indicator, unticked(0) = uniform, ticked(1) = exponential
maxdelaycuetovacuum | maxdelaycuetovacuum | maximum delay to vacuum after cue turns on. Change this if different cues have different delays to reward
Inter-trial Interval Section | meanITI | meanITI | average inter-trial-interval (ITI)

Background rewards section | backgroundsolenoid | backgroundsolenoid | designated background solenoid
| | | number
| T_bgd | T_bgd | background reward period, 1/lamba (ms)
| r_bgd | r_bgd | background solenoid open time (ms)
| mindelaybdgtocue | mindelaybgdtocue | minimum delay between a background solenoid and the next cue (ms)
| mindelayfxdtocue | mindelayfxdtocue | minimum delay between fixed solenoid to the next background solenoid (ms)
| trialbytrialbgdsolenoidflag | trialbytrialbgdsolenoidflag | flag to run experiment with background solenoid rates changing on a trial-by-trial basis if==1
| totPoisssolenoid | totPoisssolenoid | total number of background rewards to give per session


Experiment mode selection | experimentmode | experimentmode | signal which experiments to run. If experiment mode==1, run with cues; if==2, only give background Poisson rewards; if==3, give lick dependent rewards etc.
Lick for rewards properties window | reqlicknum[2] | reqlicknum[0-1] | number of licks required on side lick tube 1 and 2 to receive reward from middle lick tube
| licksolenoid[2] | licksolenoid[0-1] | associated solenoid number for licking lick tube 1 and 2


lickprob[2] | lickprob[0-1] | probability of solenoid opening upon completing required licks on side lick tube 1 and 2
lickopentime[2] | lickopentime[0-1] | solenoid open time (ms)
delaytoreward[2] | delaytoreward[0-1] | delay to solenoid/reward after the last required lick
delaytolick[2] | delaytolick[0-1] | delay to start counting the next lick after reward consumption
minrewards[2] | minrewards[0-1] | minimum number of rewards to give for each session
signaltolickreq[2] | signaltolickreq[0-1] | cue type signaling lick requirement met, 1=sound, 2=light, 3=both
soundsignalpulse[2] | soundsignalpulse[0-1] | whether the cue signal is pulsed or not, 0=not pulsed, 1=pulsed
soundfreq[2] | soundfreq[0-1] | auditory signal frequency (in kHz)
sounddur[2] | sounddur[0-1] | both sound and light cue duration (ms)
lickspeaker[2] | lickspeaker[0-1] | speaker number for auditory cues
variableratioflag[2] | variableratioflag[0-1] | flag for variable ratio schedule for lick requirements, if=1, then the task is a variable ratio schedule, if=0, fixed ratio schedule
variableintervalflag[2] | variableintervalflag[0-1] | flag for variable interval schedule for lick requirements, if=1, variable interval schedule task, if=0, fixed interval schedule
fixedsidecheck[2] | fixedsidecheck[0-1] | for delay discounting task, if=0, selected lick tube is not a fixed side, give rewards opening time

| | varies from 0-60ms, if=1, selected lick tube is a fixed side with opening of 30ms.
licklight[2] | licklight[0-1] | light number for light cues


| | (ms)
laserduration | laserduration | laser on duration (ms)
randlaserflag | randlaserflag | flag to run sessions with laser turning on randomly if==1
laserpulseperiod | laserpulseperiod | period for which laser is on in a cycle (ms)
laserpulseoffperiod | laserpulseoffperiod | period for which laser is off in a cycle (ms); If equal to laserpulseperiod, duty cycle is 50%
lasertrialbytrialflag | lasertrialbytrialflag | flag to turn laser on a trial-by-trial basis
CS1lasercheck | CS1lasercheck | laser-on flag for CS1, 1==laser on, 0==laser off
CS3lasercheck | CS2lasercheck | laser-on flag for CS2, 1==laser on, 0==laser off
CS3lasercheck | CS3lasercheck | laser-on flag for CS3, 1==laser on, 0==laser off
CS4lasercheck | CS4lasercheck | laser-on flag for CS4, 1==laser on, 0==laser off
Rewardlasercheck | Rewardlasercheck | laser-on flag for reward, 1==laser on, 0==laser off
Laser / Optogenetics section | laserlatency | laserlatency | laser latency with respect to cue

*Order of the parameters saved in MATLAB/Arduino generally follows this chart with some exceptions of newly added parameters saved at the end. †Brown inked parameters were not demonstrated in the behavioral tasked listed in the paper but can be useful for other tasks and manipulations

General Programming Logic
In general, the idea is that the Arduino controls each experiment. Thus, the primary code is the Arduino code for each experiment. In this code, all processing is eventbased. Thus, the Arduino keeps track of time since the start of the experiment and checks if the time for a new event has come and if so, it executes that event, updates time for the next events, and goes back to check whether it is time for each new event, etc. To make the program as easy as possible for a user to run (i.e., without programming knowledge), the user-facing part of the code is only the MATLAB GUI. In this GUI, the users can set the experiment mode, parameters for the experiments, test hardware, receive timestamps for events from Arduino and visualize the behavior in real time. If one separate MATLAB process is opened per behavioral box and each Arduino is connected via a separate USB cable to the computer running the MATLAB instances, the task can be run in parallel for multiple behavior boxes.

Possible tasks
Here, we list the possible behavioral tasks that can be run using B-CALM, including a few planned extensions being worked on currently. Please note that the MATLAB GUI is currently built using GUIDE. However, we are porting this code away from GUIDE to increase compatibility across MATLAB versions. All current codes were tested on MATLAB v2021b.

Pavlovian conditioning
Pavlovian delay or trace conditioning with arbitrary reward magnitude, probability, or delays, and two possible reward/punishment identities for up to three trial types (one trial type per conditioned stimulus). We are currently extending this to a fourth conditioned stimulus. Please also note that the reward identities can be changed by simply changing the liquid in the containers attached to the central liquid dispensing solenoids. Though only two separate liquids can be delivered within a single behavioral session, different liquids can be delivered across different sessions. Possible liquids include water, sucrose, flavored sucrose, flavored milk, quinine, alcohol, orally deliverable drug solutions etc. Other currently possible parameters include:
- Intertrial interval (ITI): currently, we can set the intertrial interval to be exponentially distributed (i.e., with flat hazard function), uniformly distributed, exponentially distributed between cue-to-cue (instead of reward-to-cue), exponentially distributed and independent for both cue and reward (this is Rescorla’s “truly random control”), or exponentially distributed between rewardto-reward (with cue coming after reward, i.e., backward conditioning). These are available in the “interval distribution” drop down menu.
- Stimulus (sound/light) properties: The frequency of the sound, whether or not it is pulsing (turns on and off with a period of 200 ms; hardcoded into the corresponding Arduino program), or whether it is a chirp with a frequency increase or decrease (“Increasing cue(1) or not”) can be set. For a light, one of two possible LEDs can be turned on (“Light number”).

- Unpredictable rewards during ITI for contingency degradation: It is possible to deliver unpredictable rewards during the ITI at a defined rate to reduce the contingency between a cue and reward. This is editable in the “Background rewards” section of the GUI (see below).
- Optogenetics laser: It is possible to control when a laser turns on relative to the cue onset, its duration, pulse on and pulse off period, which trial types the laser is activated on, whether the laser should be delivered pseudorandomly only in half of the trials (“Trial-by-trial?” checkbox), and whether the laser should be delivered randomly during the ITI. These are available in the “Optogenetics” panel.
- Multiple cues on the same trial: In some cases, it is necessary to deliver two cues on the same trial. This is the case for blocking, sensory preconditioning, occasion setting, or biconditional discrimination. For these experiments, set CS second cue type to 1= sound or 2 = light. Indicate the delay for second cue—this is the delay between first cue onset and second cue. In this case, the cue duration for both stimuli are set to be equal (set in “Cue duration”), and the “delay to solenoid” is measured from the second stimulus. Set the second cue properties such as second cue frequency, speaker number or light number accordingly. Please note that all solenoids are delivered after second cue onset which means delays to solenoids should account for the delay between first cue and second cue and cannot be shorter than delay to second cue.

Operant conditioning
Operant conditioning with licking on left/right lick tubes to get rewards on the center lick tube. This design allows operant action (lick left/right) to be separated from the consummatory action (lick center). Possible schedules include fixed ratio, variable ratio, fixed interval, variable interval, or their mixtures. In self-administration like variants, a conditional stimulus can be delivered immediately prior to reward delivery.
These parameters are set in the sections of the GUI shown below.


Figure 11 Operant conditioning task parameter setting example

Cue-action-reward tasks
A discriminative stimulus based operant conditioning task (more generally, a cue-action-reward task) can be run such that an animal needs to perform an operant action (lick left/right) after receiving a specific cue to obtain reward. This is set by changing the “Go lick requirement” (how many licks to get reward) and “Go lick tube (or solenoid)” (which lick tube to lick to meet the requirement; could be left, right, or center). One can also set the go lick requirement to 0 and set the reward probability to 100 but deliver a punishment (e.g., quinine) in the central lick tube. Under these settings, the animal must withhold licking to avoid receiving the punishment.
Each trial type (listed under the CS columns) can cause two solenoid openings. This is useful for either multiple reward deliveries in a trial (possibly different identities) or presenting the operant lick tubes (left/right), which are themselves mounted on solenoids that allow presentation or retraction of the lick tubes. Therefore, the solenoid related entries in the following GUI section contain a “+” sign. By activating (or not) the retraction solenoids, the operant lick tubes can either be made available for licking only during the trial period, or for the entire session. For the former scenario, set the first of the predicted solenoid (i.e., the one before the “+”) to be the solenoid controlling the retractable lick tubes for the appropriate duration of opening (corresponding to how long it should stay available during the trial). Importantly, we assume that the second solenoid (the one after the “+”) is the reward delivery solenoid. It is this solenoid whose opening is contingent on meeting the “Go lick requirement”.

These parameters are set in the sections of the GUI shown below.


Figure 12 Cue-action-reward task parameter setting example

Timing tasks
Multiple timing tasks are possible. The first is the task shown in the manuscript. Here, rewards are delivered at fixed delays between each other and during the test phase, some rewards are omitted to test whether the animals perform the consummatory action at the expected reward time. To run this, set the cue duration to zero, delay to solenoid to be “0+0”, probability of solenoid to be “0+100”, and set the ITI to be uniform and at the desired inter-reward duration (e.g., for 10s inter-reward interval, set the ITI to be 9990-10010 ms).
In the second timing task, it is possible to make animals wait a desired duration after a cue until they lick for the first time. This “ramp timing” task can be controlled using the “ramp max delay” and “ramp exponent” parameters. A variant of this task can also be run without cues to produce internally generated well-timed licking. We will publish these tasks separately, as they are novel tasks and require further characterization than is possible here.

These parameters are set in the sections of the GUI shown below.


Figure 13 Interval timing task parameter setting example

Figure 14 Ramp timing task parameter setting example

Choice tasks
For the choice task shown in the paper, animals can be presented with both operant lick tubes (left/right) for the duration of the task, with different associated reward requirements or properties. For instance, each side can have different magnitudes of rewards with different delays (delay discounting), probabilities (two-armed bandit or probability discounting), or ratio requirements (effort “discounting”). It is also possible to give choices between different types of rewards of differing magnitudes to assay subjective reward preference.
Importantly, during this experiment, the animals may sometimes develop a side preference for the left or right lick tube. If so, the buttons “Clear lick 1 rewards” or “Clear lick 2 rewards” are helpful for shaping. If these buttons are engaged, licks on the corresponding lick tube (we set lick tube 1 as the left lick tube and 2 as the right) never result in reward even if the operant criterion is met. This allows the user to rapidly adjust the task to mitigate any side preference. It is also possible to counterbalance which side the higher reward is delivered. This is controllable using the “Fixed side check” option.

These parameters are set in the sections of the GUI shown below.


Matched to sample choice tasks
Matched to sample choice task utilizes both cues within each trial for the animal to evaluate the identity of the two cues. If the second cue’s identity matches the first cue’s identity, animal is supposed to lick on one side of retraction lick tube (e.g., left) to obtain a reward—this lick tube is set in the “Go lick tube (or solenoid)” parameter, 1=left lick tube, 2=right lick tube; on the contrary, if the second cue doesn’t match the first cue (light vs sound or two sound cues with different frequencies), animal needs to lick on the other side of retraction lick tube (e.g., right) to obtain the reward. Side retraction solenoids are extended upon the onset of second cue and last for a set duration for the animal to decide within this time. Delay to those solenoids is set to equal the delay from first cue to second cue. First lick made on either side lick tubes is registered as the animal’s choice. Upon first lick, both side retraction lick tubes are retracted back. Reward is given immediately through the middle lick tube if the animal made the correct choice and no reward if otherwise. If no lick is made during the length of side lick tube extension, side lick tubes will be retracted back once time passes the duration. No reward will be given in this case and trial will end to enter the inter-trial interval.

These parameters are set in the sections of the GUI shown below.


Possible hardware modifications
Currently, our hardware is set up to perform behavioral experiments in head-fixed mice. Nevertheless, since our software is agnostic to the exact hardware connected to each Arduino pin, it is possible to change any of the hardware inputs/outputs. For instance, the side lick tubes can be swapped out with levers that can send in a TTL input for

Matched-to-sample trial Unmatched-to-sample trial every lever press to the Arduino. Another possibility is that these inputs could correspond to infrared beam breaks corresponding to nose poke entries in freely moving animals. Similarly, the solenoid control outputs that deliver rewards or retract lick tubes can be swapped with TTL-controlled motor/solenoid mechanisms that deliver solid or liquid rewards, or control retraction of levers respectively. Similarly, the TTL outputs for turning on the lights can be connected to deliver other types of sensory stimuli that take TTL inputs for turning on/off. If more complex stimuli are needed, one possibility is to control them with a separate microcontroller and have them turn on/off based on a TTL input. In this case, one would need to synchronize the clocks of the two microcontrollers. That can be done using a similar approach as shown in Figure 3E.
In all these cases, the text on the GUI will need to be modified to match the external device. For instance, if the light is swapped with a smell, the text in the GUI may need to be switched for consistency. This can be done by opening the GUI file (“headfix_GUI.fig”) in GUIDE and changing the corresponding texts. Please note that in the future, we are planning to port our code away from GUIDE for better compatibility across MATLAB versions.

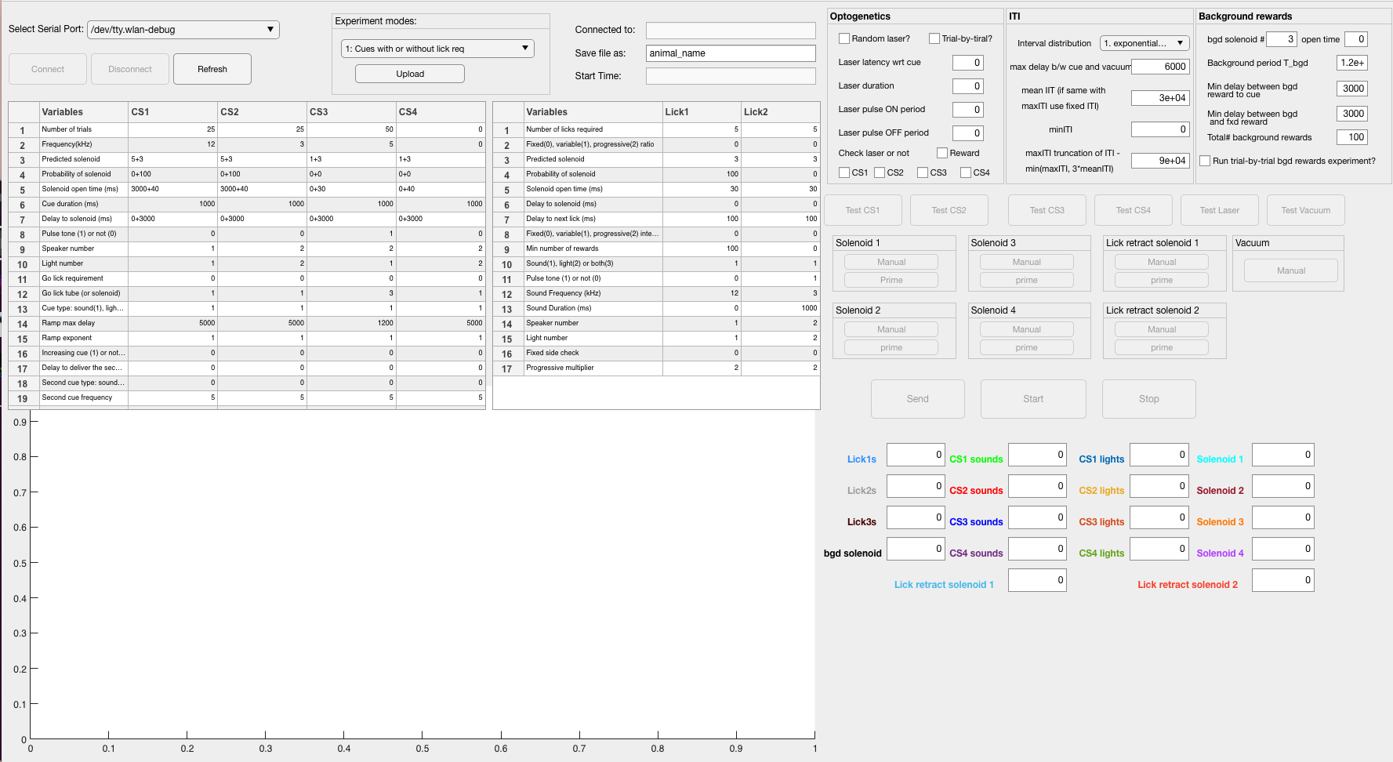
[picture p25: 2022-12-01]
task codes/programmatic GUI/screenshot.png

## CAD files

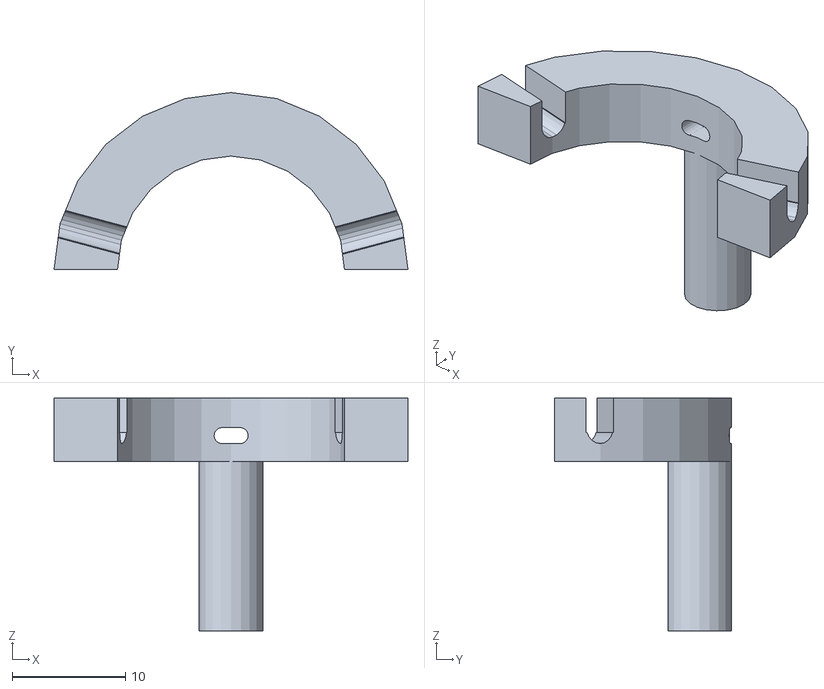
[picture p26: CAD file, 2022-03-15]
head_fixed_setup/3D printing files/Final_2_lick_tube_holder_levelholes.stl
31.2 x 15.6 x 20.5

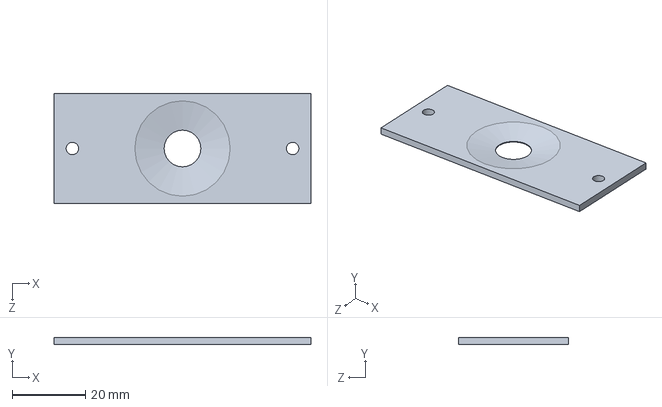
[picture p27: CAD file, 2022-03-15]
head_fixed_setup/CAD files/Original_holdertop.SLDPRT
70.0 x 2.00 x 30.0 mm

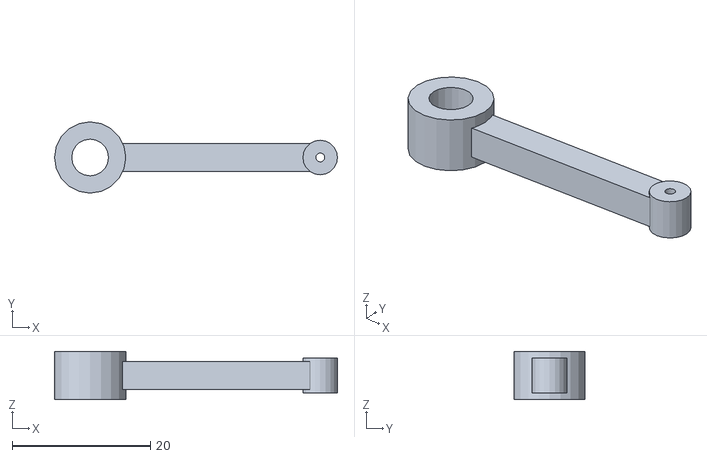
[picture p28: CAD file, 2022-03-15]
head_fixed_setup/3D printing files/Final_left_retraction_solenoid_attachment.stl
40.9 x 10.3 x 7.00

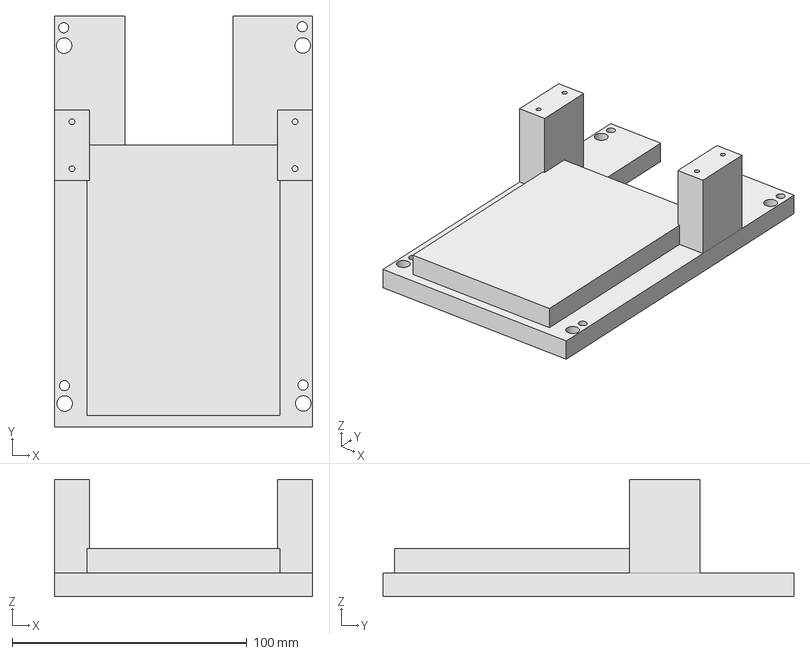
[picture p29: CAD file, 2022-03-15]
head_fixed_setup/CAD files/base design clean.step
110.0 x 175.0 x 50.0 mm

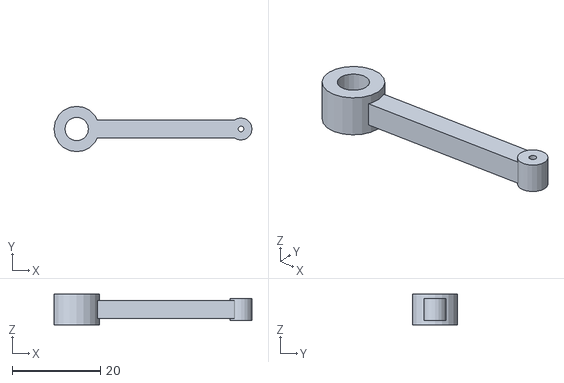
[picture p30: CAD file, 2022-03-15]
head_fixed_setup/3D printing files/Final_right_retraction_solenoid_attachment_30mm.stl
44.9 x 10.3 x 7.00

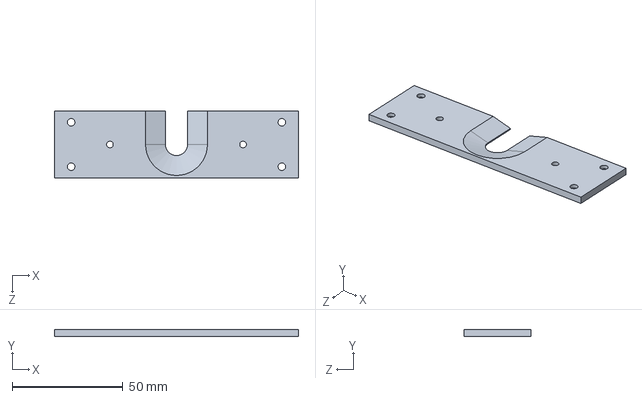
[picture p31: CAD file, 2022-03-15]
head_fixed_setup/CAD files/Original_holderbottom_mod.SLDPRT
110.0 x 3.00 x 30.0 mm

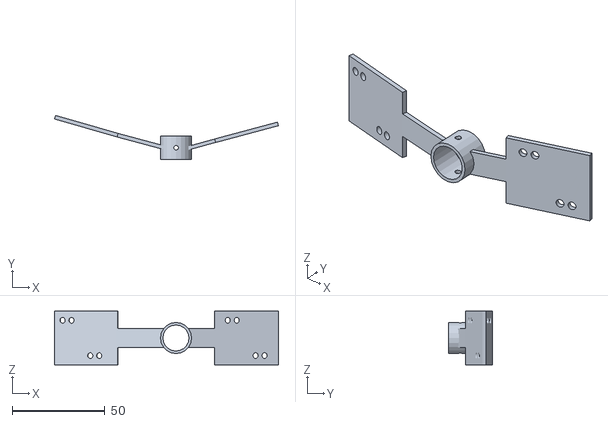
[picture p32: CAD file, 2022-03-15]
head_fixed_setup/3D printing files/Final_retraction_solenoid_wing_holder.stl
120.4 x 23.7 x 29.0

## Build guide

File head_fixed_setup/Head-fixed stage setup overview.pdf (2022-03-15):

Building Instruction for head-fixed stage:

1. Attach four 3-inch-thick posts onto the right end of an optical breadboard with ¼”-20 x ¾” setscrews to create a 6-inch by 4-inch rectangle.
2. Place aluminum head-fixed stage (CAD file available) on the four posts and stabilize with four 8/32 x ¾” cap screws.

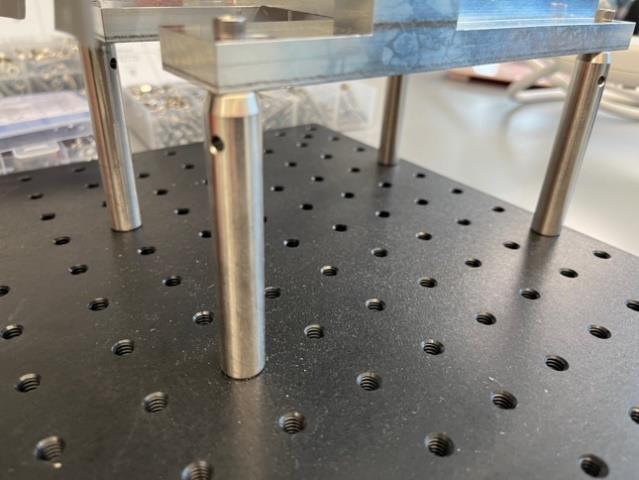
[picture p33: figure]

Figure 1 Head-fixed stage supported by four posts on breadboard

3. Place head ring holder bottom (CAD file available) onto the head stage and stabilize with two M3*12 cap screws. Then, stabilize the head ring holder top (CAD file available) with two M3*8 cap screws. Finished look below.

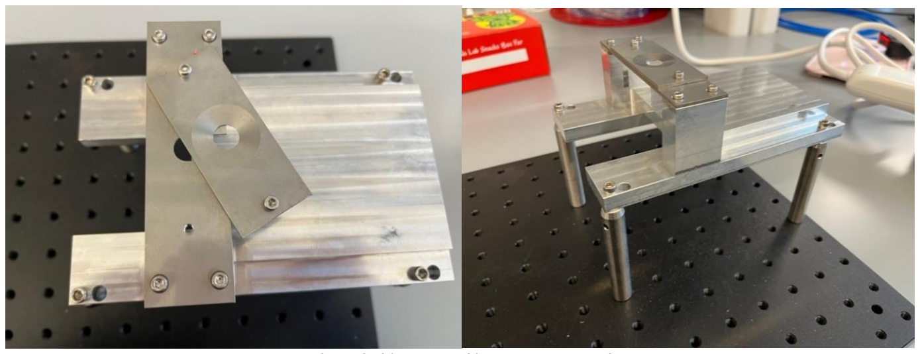
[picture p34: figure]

Figure 2 Head ring holder top and bottom setup on the stage

4. Place a clamping fork on the left side of the stage and clamp a pedestal base inside for holding the translation stages.

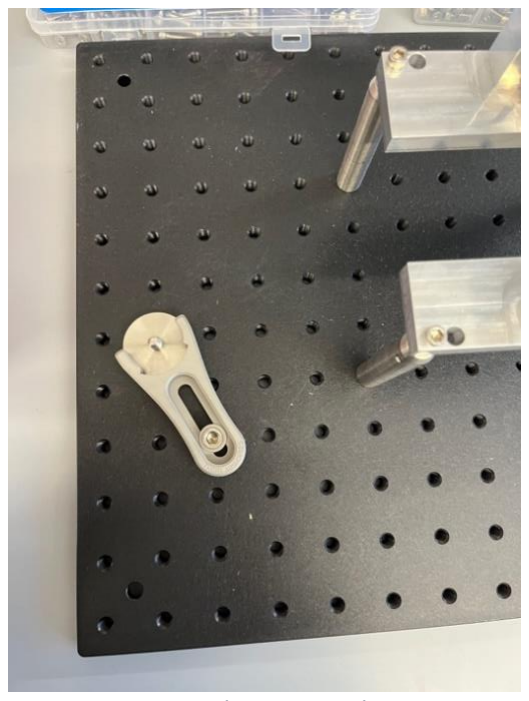
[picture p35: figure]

Figure 3 Translation stage base

5. Connect two translation stages together with a 8-32 x 5/8” setscrew to make the X and Y stages.
6. Use two 8-32 x 3/8” cap screws to connect the Y and Z stages with an angle bracket in between (see photos attached).

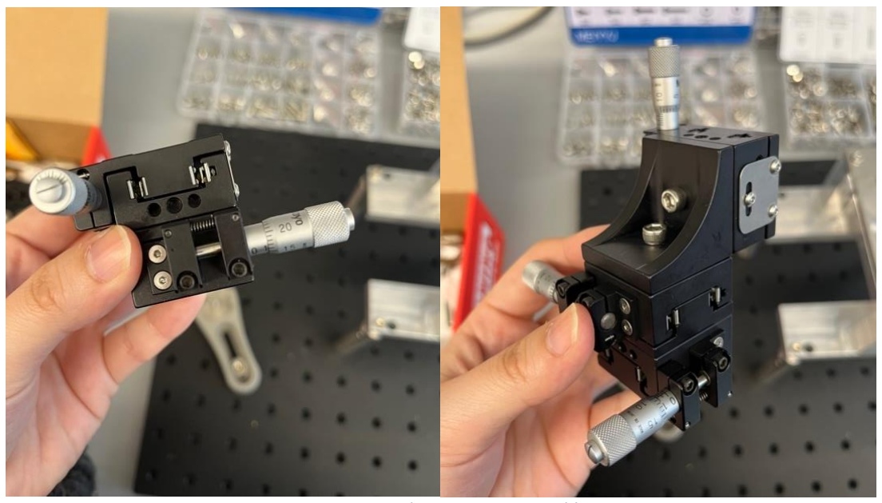
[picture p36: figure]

Figure 4 Translation stages assemble

7. Place a 1-inch post holder onto the pedestal base and a 1.5-inch post inside of the tube holder. Stabilize the post holder and post.
8. Attach the XZY stages onto the 1.5-inch post with an 8-32 x 5/8” setscrew. The correct orientation of the XYZ stages is shown below. Make sure to stabilize the system.

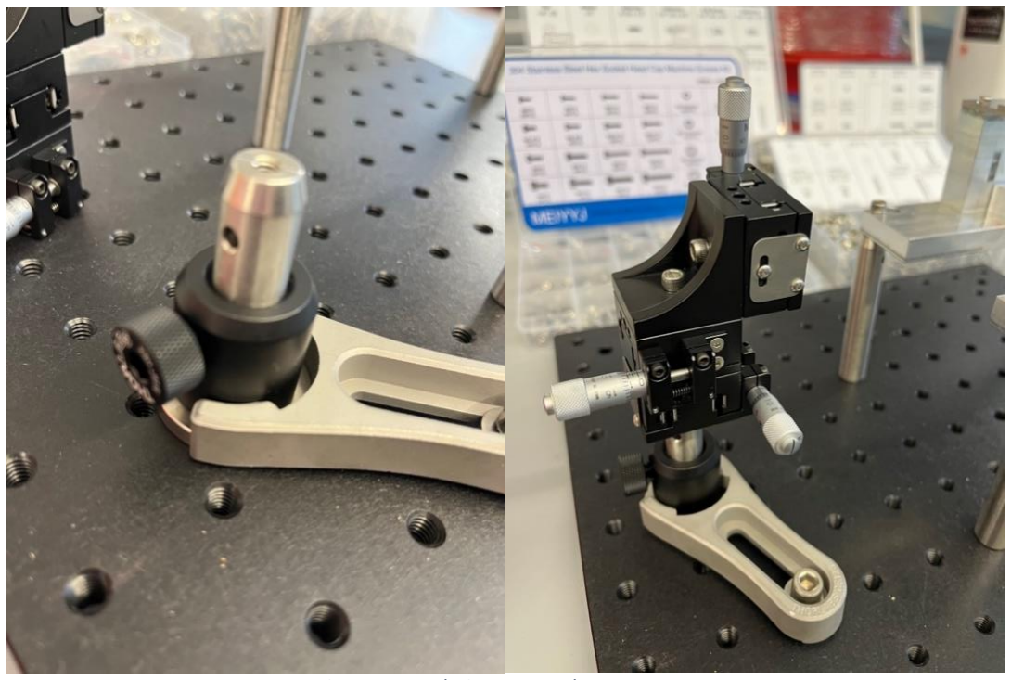
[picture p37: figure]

Figure 5 Translation stages placement

9. Connect two 1-inch-thick posts together with a ¼”-20 x ¾” setscrew, and connect one end of this combined 2-inch post to the Z stage with a 8-32 x ½” setscrew.
10. Connect the other end of the combined 2-inch post with a thin 1-inch post with a 8-32 to 4-40 inch adapter.

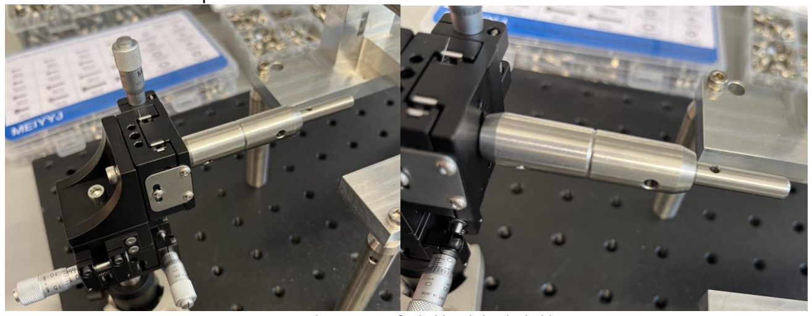
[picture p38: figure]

Figure 6 Tube extension for holding lick tube holders

11. Place the 3D printed linear retraction solenoid wing holder onto the combined 2-inch posts.
12. Place the right-angle post clamp onto the 1-inch thin post to hold the other lick tube holder.
13. Place the lick tube holder inside of the right-angle post clamp. Finished look below.

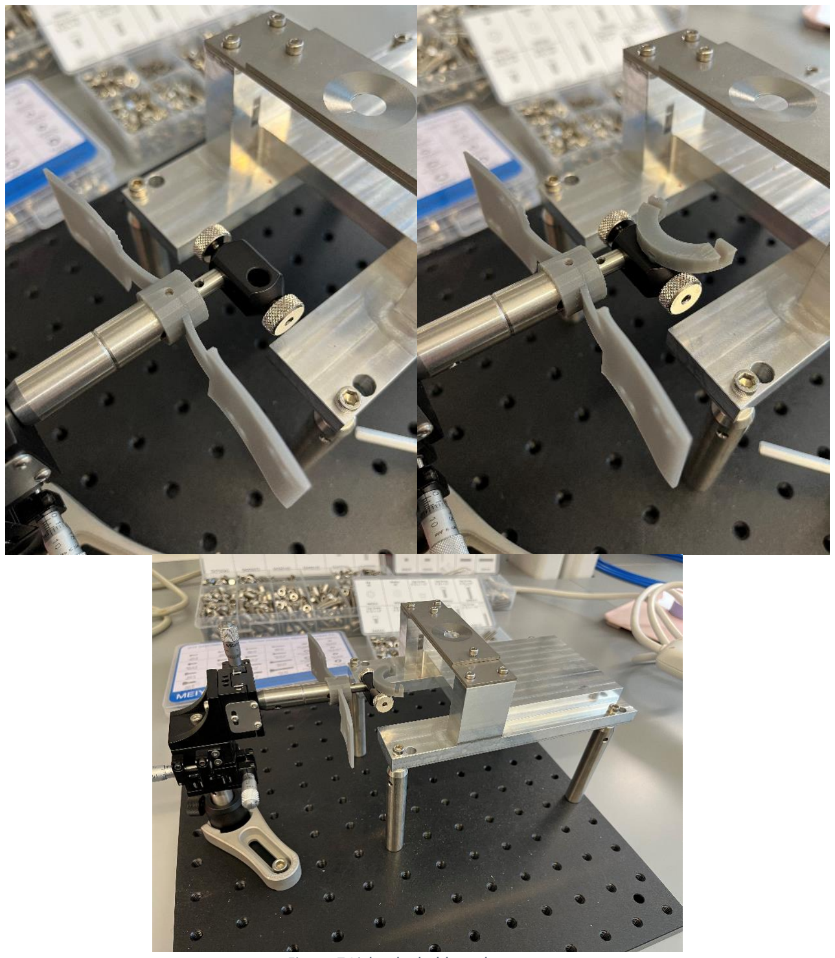
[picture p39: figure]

Figure 7 Lick tube holders placement

14. Attach two linear actuator lick retraction solenoids on the wing holder with two M2.5*6 cap screws and nuts.
15. Use an 18-guage cannula to solder four 4-to-5-inch cannulas as lick tubes. Fit two of these lick tubes into the linear actuator solenoid attachment piece’s small holes (see below).

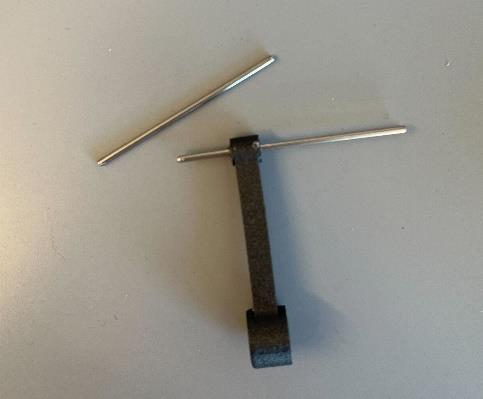
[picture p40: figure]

Figure 8 Soldered lick tubes and placement in the linear retraction solenoid attachment piece

16. Attach the two attachment pieces onto the retraction solenoids. Make sure both lick tubes fit in the side opening slots on the middle tube holder.

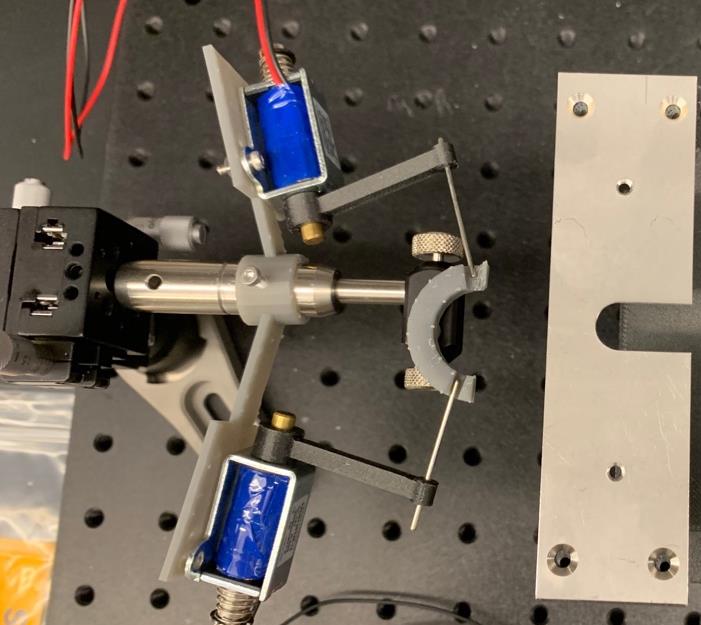
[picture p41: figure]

Figure 9 Adding lick retraction solenoids and lick tubes via 3D printed attachments

17. Connect the third soldered lick tube to one end of a 4-feet long 1/16" ID x 1/8" OD Ester tubing with a 1/8" x 1/16" coupler adapter.

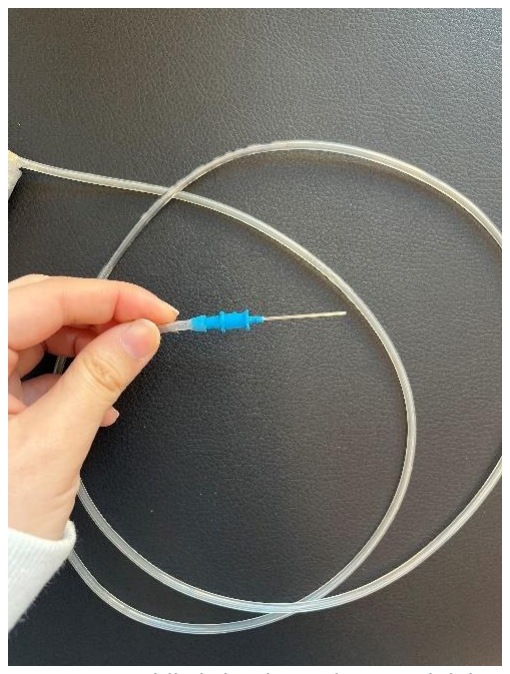
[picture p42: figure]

Figure 10 Connect middle lick tube with reward delivery tubing

18. Connect the other end of the tubing to an opening of the Parker solenoid. Next, connect the other opening of the solenoid to a half ft long 1/16" ID x 1/8" OD Ester tubing. Place another 1/8" x 1/16" coupler adapter at the end of that tubing.

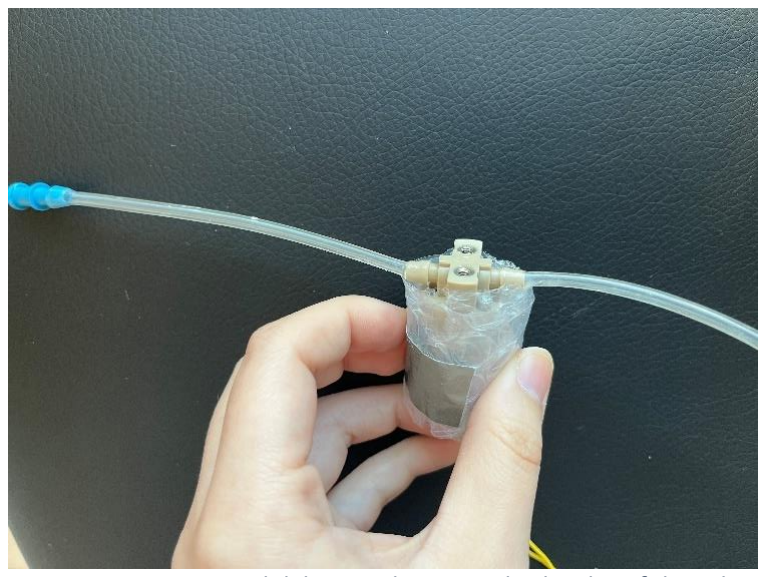
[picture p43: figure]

Figure 11 Connect reward delivery tubing onto both sides of the solenoid

19. Connect the other end of the 1/8" x 1/16" coupler adapter to a 10ml syringe with an 18-gauge blunt needle. Attach the solenoid and syringe system on the outside of the behavior box with hook and loop tapes. Fluid reward will be added to the syringe during experiments.

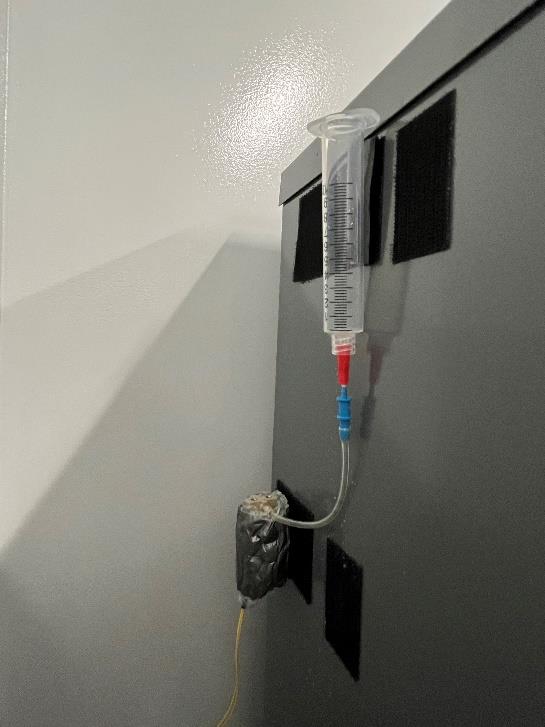
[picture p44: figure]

Figure 12 Reward delivery system view from outside of the behavioral box

20. Place the middle lick tube into the middle hole of the middle lick tube holder. In our lab, we place two lick tubes for stability purposes. At the moment, only one lick tube is connected to the fluid delivery system, but both lick tubes can be connected to different solenoids if needed.

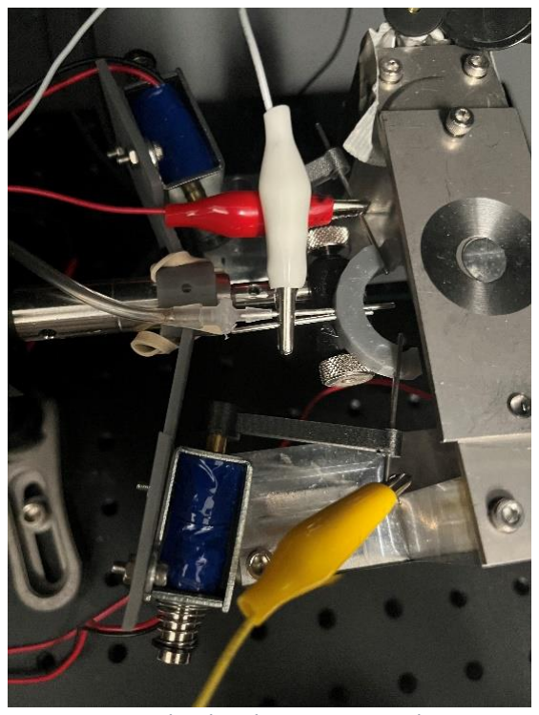
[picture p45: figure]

Figure 13 Lick tube placement complete view

21. Using alligator clips, connect lick detectors with lick tube to desired pins on the plastic box terminal blocks (exterior side). Place all hardware components to desired locations around the head-fixed stage. For example, our lab taped two speakers on the side of the post next to the head-fixed holders.

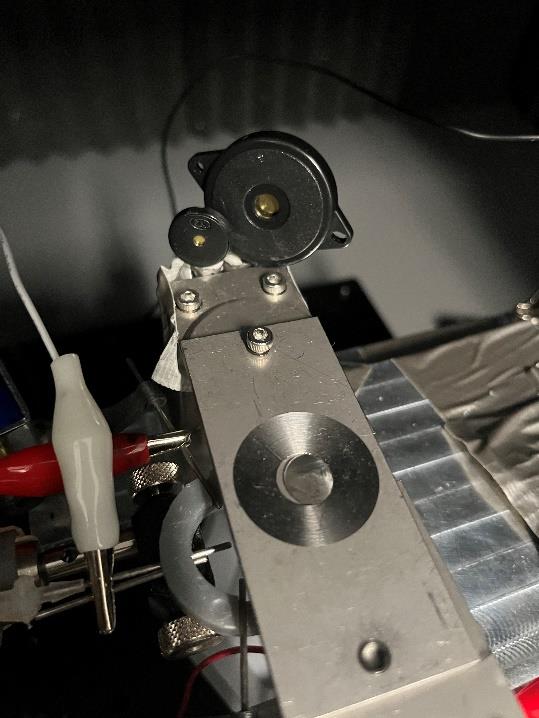
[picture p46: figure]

Figure 14 Example of speakers placement on the head-fixed stage

22. Place the head-fixed stage inside of the aluminum behavioral box with the complete circuit board and white noise machine.
23. Use adhesive spray to attach the acoustic foams on the walls inside of the box for sound-proofing purposes.

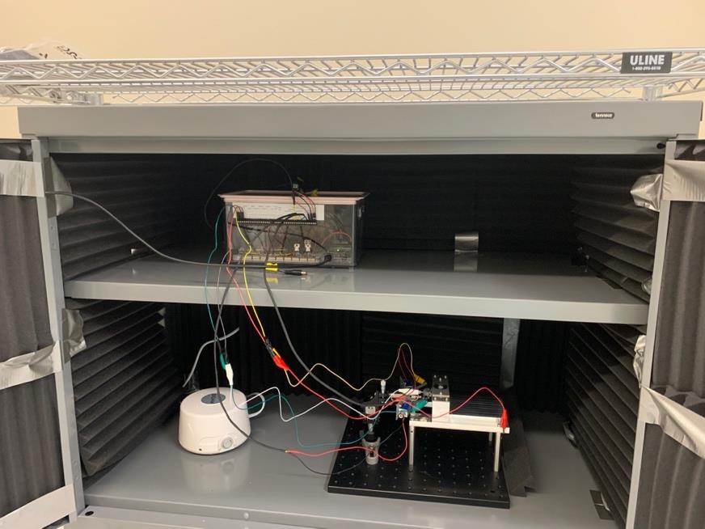
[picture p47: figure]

Figure 15 Final look of behavioral box setup

# Appendix

## A.3D printing files overview

## Middle lick tube holder

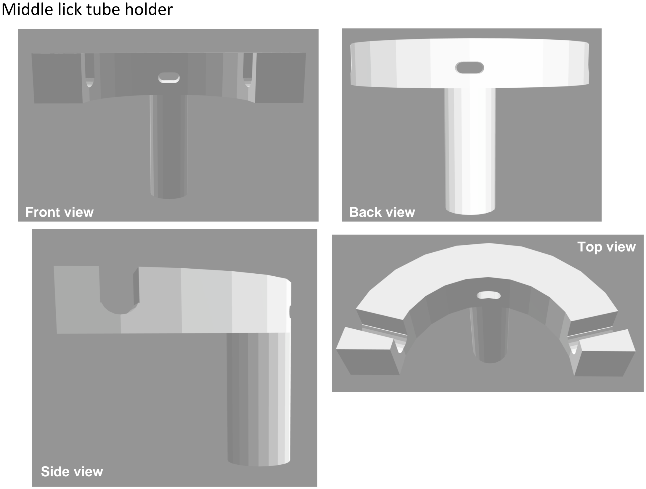
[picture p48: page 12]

Front view | Back view

Side view

Top view

## Side lick tube holder

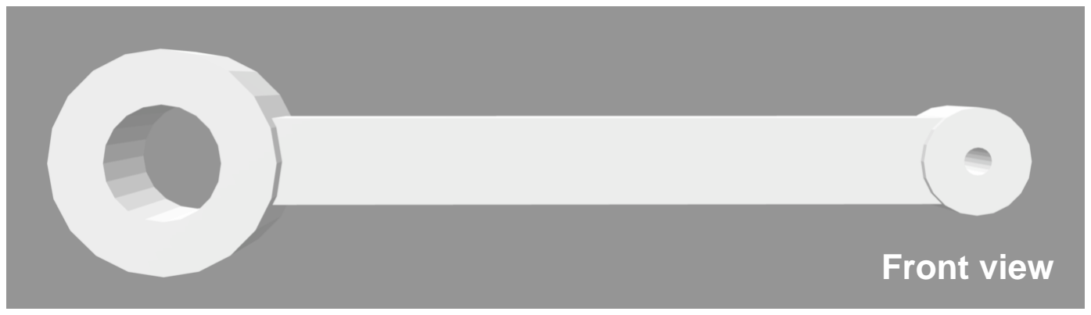
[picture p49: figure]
Front view
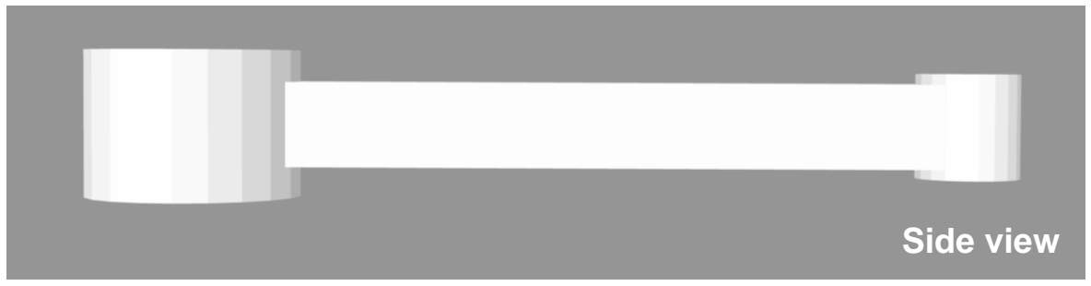
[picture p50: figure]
Side view

## Linear actuator solenoid wing holder

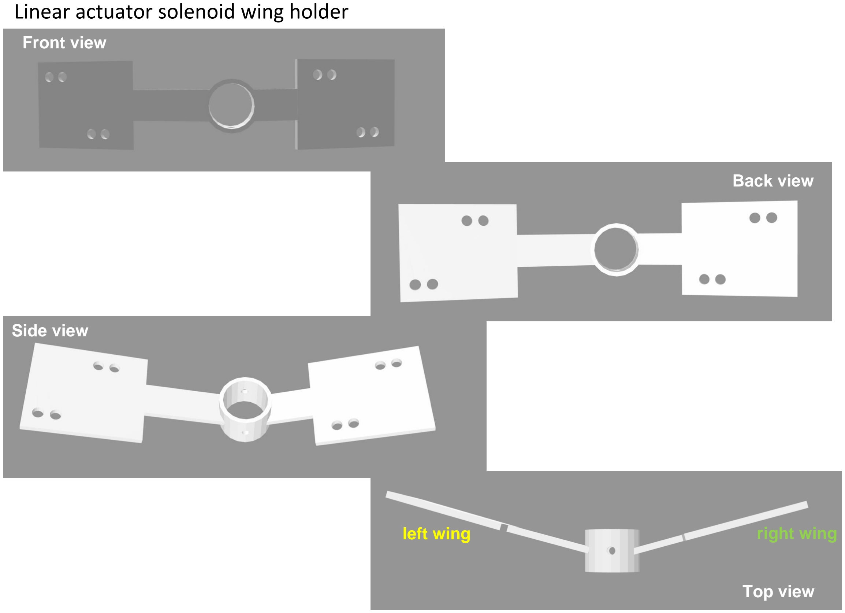
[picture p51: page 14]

Front view

Top view

Back view

Side view

left wing | right wing

## B.Lick tube position placement instructions

Instructions of setting up lick tube positions & training animals to lick prior to experiments
1. Before each task starts, we train animals sitting in head-fixed stages to lick for random sucrose rewards.
a. On the first day, animals are not familiar with the position or existence of the lick tube so we initially position the lick tube just a little underneath and close to the mouse’s mouth to let the animal know that there is a lick tube delivering sucrose drops (stage 1).
b. As the animal starts actively licking, we slowly retract the lick tube position away from the animal’s mouth to allow tongue extension to consume the sucrose at a more comfortable position (stage 2). The front half of the animal’s tongue should reach the lick tube. This process is typically carried out over 5-10 drops of sucrose delivery.

Figure 16 Mouse lick position transition

c. We then train animals on 100 random rewards trials for about 2-3 days depending on the animals’ licking. We check for the animals to reach at minimum 1000 licks over the random rewards session (20 minutes) to demonstrate that this animal is motivated enough, knows lick tube position, and can be moved to the actual experiment.
2. For the cue-action-reward task, it’s important to position the side lick tube at an appropriate distance for the animal to perform an action and then consume rewards in the middle lick tube. This is to ensure that the animal isn’t accidentally licking both tubes at the same time. We train the animals to lick the side lick tube starting at position 1 for 3 days and move to position 2, etc. (see below). If animals fail to lick on advanced positions, we move back to the previous position for longer training.
3. For the operant task and choice task, we conduct the random rewards sessions first and then place the side lick tubes at around position 2-3 for animals to lick.
Stage 1 | Stage 2

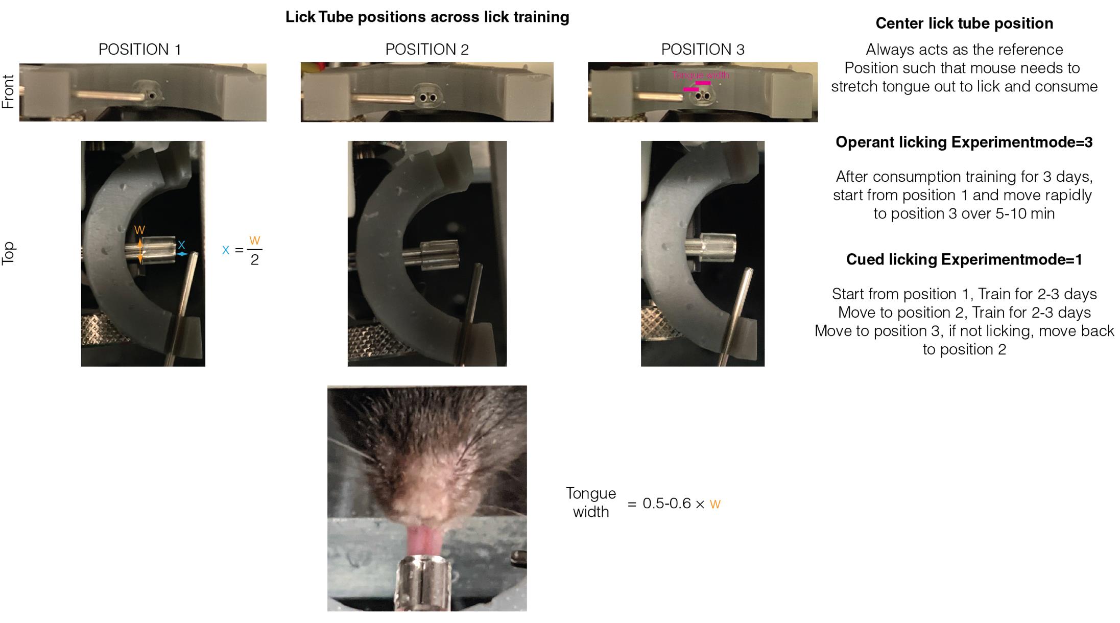
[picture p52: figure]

Figure 17 Lick tube positions across training (both lick tubes in the middle are used)

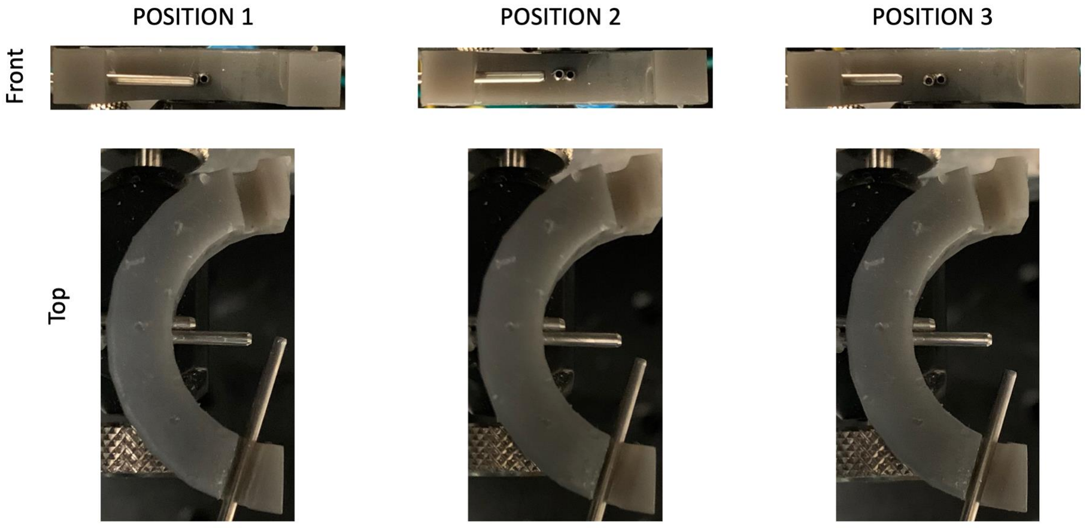
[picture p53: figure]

Figure 18 Lick tube positions across training (only one lick tube in the middle is used)

## C.Head-fixed stage parts purchase information

Item Name | Function | Vendor/ manufacturer part # | Quantity per system | Unit Cost ($) | Link
Optical breadboard | To place all the head-fixed set up | Thorlabs MB12 | 1 | 155.53 | https://www.thorlabs.com/thorproduct.cfm?partnumber=MB12
3 inch thick post | Hold heat-fixed stage up | Thorlabs TR3-P5 | 4 | 5.02 | https://www.thorlabs.com/thorproduct.cfm?partnumber=TR3-P5
Clamping fork | Clamp the post onto breadboard | Thorlabs CF125C-P5 | 1 | 11.13 (5 pack) | https://www.thorlabs.com/thorproduct.cfm?partnumber=CF125C-P5
1.5 inch thick post | Hold translation stages | Thorlabs TR1.5-P5 | 1 | 4.6 | https://www.thorlabs.com/thorproduct.cfm?partnumber=TR1.5-P5
1 inch post holder | To hold the 1.5 in post | Thorlabs PH1-P5 | 1 | 7.24 | https://www.thorlabs.com/thorproduct.cfm?partnumber=PH1-P5#ad-image-0
Pedestal base | Base for the above post and post holder | Thorlabs BE1 | 1 | 10.06 | https://www.thorlabs.com/thorproduct.cfm?partnumber=BE1#ad-image-0
Translation stage | Linear stages for adjusting licktube positions | Thorlabs MS1S | 3 | 227.25 | https://www.thorlabs.com/thorproduct.cfm?partnumber=MS1S
Angle bracket for MS translation stages | To make XZY translation stage mounts | Thorlabs MS102 | 1 | 33.83 | https://www.thorlabs.com/thorproduct.cfm?partnumber=MS102
1 inch thick post | To extend and hold licktube holders | Thorlabs TR1-P5 | 2 | 4.4 | https://www.thorlabs.com/thorproduct.cfm?partnumber=TR1-P5
8-32 to 4-40 adapter | To hold the above two 1 inch thick posts together | Thorlabs AP8E4E | 1 | 2.1 | https://www.thorlabs.com/thorproduct.cfm?partnumber=AP8E4E#ad-image-0
1 inch thin post | To hold licktube holders | Thorlabs MS1R | 1 | 6.77 | https://www.thorlabs.com/thorproduct.cfm?partnumber=MS1R
Right angel post clamp | To hold lick tube holder onto the post | Thorlabs MSRA90 | 1 | 17.85 | https://www.thorlabs.com/thorproduct.cfm?partnumber=MSRA90
8-32 Cap Screw and Hardware Kit | Used for connecting 3 inch posts to the head-fixed base and connecting translational parts with angle bracket | Thorlabs HW-KIT1 | 1 | 61.14 | https://www.thorlabs.com/thorproduct.cfm?partnumber=HW-KIT1
1/4“ -20 Cap Screw and Hardware kit | To hold posts to optical breadboard and other parts | Thorlabs HW-KIT2 | 1 | 121.1 | https://www.thorlabs.com/thorproduct.cfm?partnumber=HW-KIT2
8-32 Setscrew and | To hold translational stages together and other parts | Thorlabs HW-KIT3 | 1 | 121.2 | https://www.thorlabs.com/thorproduct.cfm?partnumber=HW-KIT3

Head-fixed
stage setup

| Hardware Kit
| M2-M4 head cap screws set | To hold head ring stable between top and bottom ring attachment piece | MEIYYJ 0759337318592 | 1 | 29.99 | https://www.amazon.com/MEIYYJ-Stainless-Machine-Assortment-Tweezers/dp/B08FT933MM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
| 1/16" ID x 1/8" OD x 1/32" Wall Superthane ® Ester-Based Tubing | Delivers fluids | US Plastic 56400 | 4 ft | 0.16/ft | https://www.usplastic.com/catalog/item.aspx?catid=717&itemid=66285
| 1/8" x 1/16" Eldon James™ Anti microbial HDPE Reducing Coupler | Connects the above tubing to 18G needle and lick tube | US Plastic 65611 | 2 per lick spout / fluid delivery | 0.59 | https://www.usplastic.com/catalog/item.aspx?itemid=114542
| 10 ml Syringe | Contains fluid for delivery | Fisher Scientific 14-955-459 | 1 | 2.05 | https://www.fishersci.com/shop/products/sterile-syringes-single-use-12/14955459
| Blunt tip 18-gauge needle | Connects syringe to tubing for liquid delivery | BD 305181 | 1 | 0.15 | https://www.esutures.com/product/0-in-date/119-bd/667-needles/46340600-bd-blunt-fill-needle-18g-x-1-305181/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
| 18-gauge cannula | Soldered as lick tubes | Component supply HTX-18R | 8 in | 0.2/ in | https://componentsupplycompany.com/product-pages/hypodermic-metric.php
Behavioral box setup | Behavioral box | Box to store head-fixed setup | Global industrial WGB2236106 | 1 | 313.95 | https://www.globalindustrial.com/p/standard-kd-desk-height-storage-cabinet-36-w-x-18-d-x-30-h-medium-grey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
| White noise generator | To produce white noise inside of behavioral box | Marpac M1DSUSWH | 1 | 44.99 | https://www.amazon.com/Marpac-Classic-White-Noise-Machine/dp/B00HD0ELFK?th=1
| Acoustic foam | Sound-proof and absorption acoustic panels for behavioral ox walls | Acoustic Panels B091CD4KYB | 1 pack | 17.99 | https://www.amazon.com/gp/product/B091CD4KYB/ref=ppx_yo_dt_b_asin_title_o00_s00?ie=UTF8&th=1
| Adhesive spray | To attach acoustic foams on box walls | The Gorilla Glue Company 6314410 | 1 | 18 | https://www.amazon.com/gp/product/B07MY28DYX/ref=ppx_yo_dt_b_search_asin_title?ie=UTF8&th=1

Fluid delivery
system

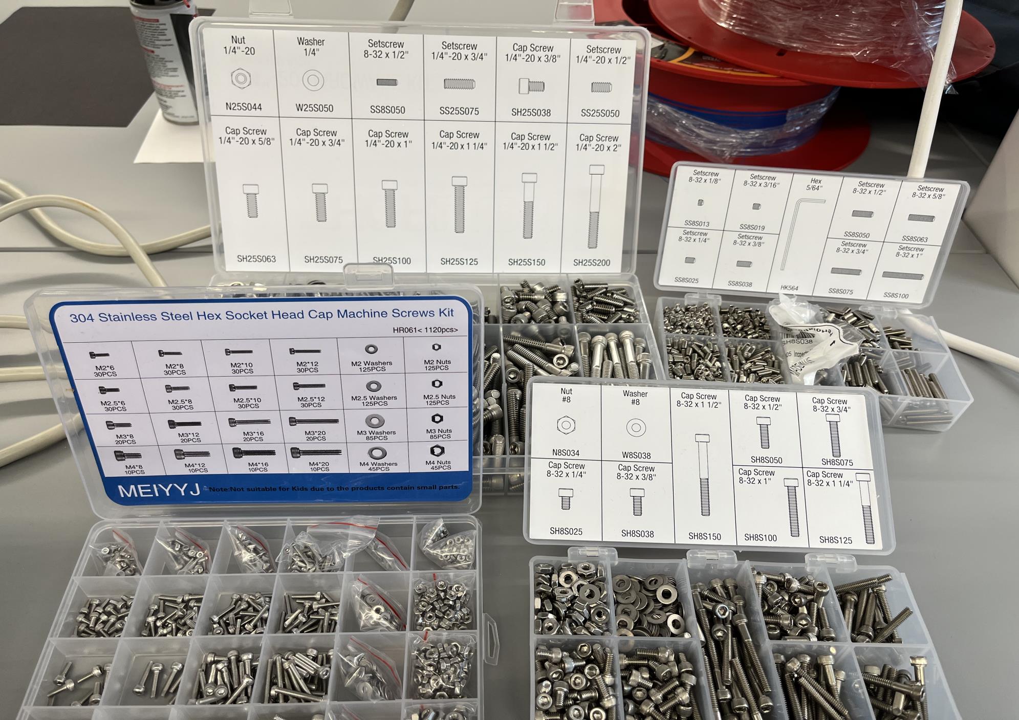
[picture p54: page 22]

Figure 19 Screwset reference

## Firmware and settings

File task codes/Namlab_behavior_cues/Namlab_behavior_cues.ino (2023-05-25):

// The original script sets trial-by-trial LASER randomly on 50% of the trials (shuffled) without consideration of whether a trial is CS+ or CS-
// Here, there are going to be 0.8*numCSminus (=40) CS+ laser trials and 0.8*numCSminus (=40) CS- laser trials with 10 each being laser off.
// Added on 8/22/2016

// Records event from pin 'lick' and sends it
// through serial port as the time of event from the
// "start". Cues will be triggered throgh pin "cue".
// Designed to be used with MATLAB.
//
// Program will wait for signal from MATLAB containing paramenters for experiment. Following parameters need to be in the format xxx+xxx+xxx+xxx+xxx+xxx+xxx+xxx+xxx+xxx+xxx+xxx+xxx
// Every temporal parameter is expressed in units of milliseconds. Parameters to be set in MATLAB include

//Parameter meaning 
//0) number of CS1 trials
//1) number of CS2 trials
//2) number of CS3 trials
//3) number of CS4 trials
//4) frequency(kHz) of CS1 tone
//5) frequency(kHz) of CS2 tone
//6) frequency(kHz) of CS3 tone
//7) frequency(kHz) of CS4 tone
//8) predicted 1st fixed solenoid of CS1
//9) predicted 2nd fixed solenoid of CS1
//10) predicted 1st fixed solenoid of CS2
//11) predicted 2nd fixed solenoid of CS2
//12) predicted 1st fixed solenoid of CS3
//13) predicted 2nd fixed solenoid of CS3
//14) predicted 1st fixed solenoid of CS4
//15) predicted 2nd fixed solenoid of CS4
//16) probability of 1st fixed solenoid openning of CS1
//17) probability of 2nd fixed solenoid openning of CS1
//18) probability of 1st fixed solenoid openning of CS2
//19) probability of 2nd fixed solenoid openning of CS2
//20) probability of 1st fixed solenoid openning of CS3
//21) probability of 2nd fixed solenoid openning of CS3
//22) probability of 1st fixed solenoid openning of CS4
//23) probability of 2nd fixed solenoid openning of CS4
//24) openning time(ms) for 1st fixed solenoid of CS1
//25) openning time(ms) for 2nd fixed solenoid of CS1
//26) openning time(ms) for 1st fixed solenoid of CS2
//27) openning time(ms) for 2nd fixed solenoid of CS2
//28) openning time(ms) for 1st fixed solenoid of CS3
//29) openning time(ms) for 2nd fixed solenoid of CS3
//30) openning time(ms) for 1st fixed solenoid of CS4
//31) openning time(ms) for 2nd fixed solenoid of CS4
//32) cue duration(ms) for CS1
//33) cue duration(ms) for CS2
//34) cue duration(ms) for CS3
//35) cue duration(ms) for CS4
//36) delay(ms) to 1st fixed solenoid of CS1
//37) delay(ms) to 2nd fixed solenoid of CS1
//38) delay(ms) to 1st fixed solenoid of CS2
//39) delay(ms) to 2nd fixed solenoid of CS2
//40) delay(ms) to 1st fixed solenoid of CS3
//41) delay(ms) to 2nd fixed solenoid of CS3
//42) delay(ms) to 1st fixed solenoid of CS4
//43) delay(ms) to 2nd fixed solenoid of CS4
//44) flag to signal pulse tone (if==1) or not(if==0) for CS1
//45) flag to signal pulse tone (if==1) or not(if==0) for CS2
//46) flag to signal pulse tone (if==1) or not(if==0) for CS3
//47) flag to signal pulse tone (if==1) or not(if==0) for CS4
//48) speaker for CS1
//49) speaker for CS2
//50) speaker for CS3
//51) speaker for CS4
//52) number of licks required on the first fixed solenoid in order to get reward on the second fixed solenoid of CS1
//53) number of licks required on the first fixed solenoid in order to get reward on the second fixed solenoid of CS2
//54) number of licks requried on the first fixed solenoid in order to get reward on the second fixed solenoid of CS3
//55) number of licks requried on the first fixed solenoid in order to get reward on the second fixed solenoid of CS4
//56) appropriate licktube or solenoid for golickreq of CS1
//57) appropriate licktube or solenoid for golickreq of CS2
//58) appropriate licktube or solenoid for golickreq of CS3
//59) appropriate licktube or solenoid for golickreq of CS4
//60) signal for golickreq met of CS1
//61) signal for golickreq met of CS2
//62) signal for golickreq met of CS3
//63) signal for golickreq met of CS4
//64) mean intertrial interval (ITI) in ms from fixed solenoid to next tone based on exponential distirbution
//65) max ITI; truncation for exponential distribution is set at minimum of maximum ITI or 3*meanITI; if maxITI==meanITI, use fixed ITI
//66) min ITI
//67) flag to set ITI distribution. If==1, draw from exponential, if==0 draw from uniform
//68) which solenoid set to be the background solenoid
//69) background solenoid period, 1/lambda, in ms
//70) background solenoid openning time, in ms
//71) minimum delay between a background solenoid and the next cue, in ms
//72) minimum delay between fixed solenoid to the next background solenoid
//73) signal which experiment mode to run: if==1, run with cues; if==2, give only background poisson solenoids, if==3, give lick dependent rewards
//74) flag to run experiment with background solenoid rates changing on a trial-by-trial basis if==1
//75) total number of background solenoids to stop the session if experimentmode==2, only Poisson session
//76) required number of licks on lick tube 1 to get reward
//77) required number of licks on lick tube 2 to get reward
//78) predicted fixed solenoid for reward after licking lick tube 1
//79) predicted fixed solenoid for reward after licking lick tube 2
//80) probability of fixed solenoid for reward after licking lick tube 1
//81) probability of fixed solenoid for reward after licking lick tube 2
//82) opening time of fixed solenoid for reward after licking lick tube 1
//83) opening time of fixed solenoid for reward after licking lick tube 2
//84) delay time (ms) to fixed solenoid
//85) delay time (ms) to fixed solenoid
//86) delay time (ms) to activate lick tube 1
//87) delay time (ms) to activate lick tube 2
//88) minimum number of rewards delivered to lick tube 1
//89) minimum number of rewards delivered to lick tube 2
//90）signal to meet number of lick requirements of tube 1
//91) signal to meet number of lick requirements of tube 2
//92) sound signal of 70) to pulse or not
//93) sound signal of 71) to pulse or not
//94) sound signal frequency (kHz) of lick tube 1
//95) sound signal frequency (kHz) of lick tube 2
//96) sound signal duration (ms) of lick tube 1
//97) sound signal duration (ms) of lick tube 2
//98) sound signal speaker of lick tube 1
//99) sound signal speaker of lick tube 2
//100) value of the latency wrt the cue at which the laser turns on (0 for cue start; t_fxd for solenoid start)
//101) value of the duration for which the laser remains on. It can pulse within this duration
//102) flag to run sessions with laser turning on randomly if==1
//103) period for which laser is on in a cycle (ms)
//104) period for which laser is off in a cycle (ms); If equal to laserpulseperiod, duty cycle is 50%
//105) flag to turn laser on a trial-by-trial basis
//106) maximum delay to vacuum after cue turns on. Change this if different cues have different delays to reward
//107)to be such that it is longer than the longest delay to reward. Basically, this quantity measures duration of trial.
//108) light number for CS1
//109) light number for CS2
//110) light number for CS3
//111) light number for CS4
//112) variable ratio check for lick 1s. 1==variable, 0==fixed
//113) variable ratio check for lick 2s. 1==variable, 0==fixed
//114) variable interval flag for lick 1s. 1==variable, 0==fixed
//115) variable interval flag for lick 2s. 1==variable, 0==fixed
//116) light number for lick 1
//117) light number for lick 2
//118) laser on flag for CS1, 1==laser on, 0==laser off
//119) laser on flag for CS2, 1==laser on, 0==laser off
//120) laser on flag for CS3, 1==laser on, 0==laser off
//121) laser on flag for CS4, 1==laser on, 0==laser off
//122) fixed reward check for left lick tube (lick tube 1) for delay discounting task
//123) fixed reward check for right lick tube (lick tube 2) for delay discounting task
//124) reward laser check flag 1==laser, 0==no laser
//125) ramp max delay to CS1 for ramp timing task
//126) ramp max delay to CS2 for ramp timing task
//127) ramp max delay to CS3 for ramp timing task
//128) ramp max delay to CS4 for ramp timing task
//129) exponent factor for ramp function for CS1
//130) exponent factor for ramp function for CS2
//131) exponent factor for ramp function for CS3
//132) exponent factor for ramp function for CS4
//133) frequency increasing or decreasing for CS1
//134) frequency increasing or decreasing for CS2
//135) frequency increasing or decreasing for CS3
//136) frequency increasing or decreasing for CS4
//137) delay between first cue and second cue onset for CS1
//138) delay between first cue and second cue onset for CS2
//139) delay between first cue and second cue onset for CS3
//140) delay between first cue and second cue onset for CS4
//141) second cue type for CS1, 1=sound, 2=light, 0=no second cue
//142) second cue type for CS2, 1=sound, 2=light, 0=no second cue
//143) second cue type for CS3, 1=sound, 2=light, 0=no second cue
//144) second cue type for CS4, 1=sound, 2=light, 0=no second cue
//145) second cue frequency for CS1 if it's sound 
//146) second cue frequency for CS2 if it's sound 
//147) second cue frequency for CS3 if it's sound 
//148) second cue frequency for CS4 if it's sound 
//149) second cue speaker number for CS1 
//150) second cue speaker number for CS2
//151) second cue speaker number for CS3
//152) second cue speaker number for CS4
//153) second cue light number for CS1 
//154) second cue light number for CS2
//155) second cue light number for CS3
//156) second cue light number for CS4

#include <math.h>
#include <avr/wdt.h>

// Pins
int lick1     = 22;   // lick1 sensor
int lick2     = 24;   // lick2 sensor
int lick3     = 26;   // lick3 sensor
int speaker1  = 28;   // pin for speaker 1
int speaker2  = 30;   // pin for speaker 2
int light1    = 23;   // pin for light 1, light 1 is used to indicate that animal has met golickreq if CSsignal == 2 or 3;
int light2    = 25;   // pin for light 2, light 2 is used to indicate that animal has met golickreq if CSsignal == 2 or 3;
int lickretractsolenoid1 = 31;  // pin for lick retraction solenoid 1
int lickretractsolenoid2 = 33;  // pin for lick retraction solenoid 2
int solenoid1 = 35;   // pin for solenoid1
int solenoid2 = 41;   // pin for solenoid2
int solenoid3 = 43;   // pin for solenoid3
int solenoid4 = 45;   // pin for solenoid4
int framein   = 32;   // pin receiving the TTL input for frame start
int vacuum    = 38;   // pin for vacuum
int laser     = 40;   // laser to pin 9
int ttloutpin = 42;   // ttl out pin for starting imaging
int ttloutstoppin = 44; // ttl out pin for stopping imaging

// Global variables
unsigned long reading;           // variable to temporarily store data being read

unsigned long start;             // timestamp of start of session
unsigned long ts;                // current timestamp

boolean lickState[3];            // state of lickometer on all 3 licktubes
boolean licked;                  // new lick or not
boolean lickwithdrawn;           // was previous lick withdrawn or not?
boolean ITIflag;                 // are you currently in ITI? This needs to be true to give background solenoids
//boolean CSminusflag;             // is current trial a CS- trial?
boolean licktubesactive;         // signal to enter active lick tube state
boolean framestate;              // state of frame input
boolean frameon;                 // did frame input turn on?
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
void loop() {
  ts = millis() - start;               // find time since start
  reading = Serial.read();             // look for signals from MATLAB

  // Arduino outputs
  // 0 = Session ended
  // 1 = Lick1 onset
  // 2 = Lick1 offset
  // 3 = Lick2 onset
  // 4 = Lick2 offset                  // leave possible codes for a future lick tube
  // 5 = Lick3 onset
  // 6 = Lick3 offset
  // 7 = Background solenoid
  // 8 = Fixed solenoid 1
  // 9 = Fixed solenoid 2
  // 10 = Fixed solenoid 3                       // leave possible codes for future solenoid
  // 11 = Fixed solenoid 4
  // 14 = vacuum
  // 15 = CS1
  // 16 = CS2
  // 17 = CS3                                   // leave possible codes for future CS
  // 21 = light1
  // 22 = light2
  // 23 = light 3
  // 25 = both CSsound1 and CSlight1
  // 26 = both CSsound2 and CSlight2
  // 27 = both CSsound3 and CSlight3
  // 30 = frame
  // 31 = laser

  if (CSct >= totalnumtrials && sessionendtime == 0 && intervaldistribution < 3) {
    sessionendtime = ts + 5000;   // end session 5 seconds after the fixed solenoid is given (or would've been for CS-) so as to store licks occuring during this time
  }

  if ((ts >= sessionendtime && sessionendtime != 0) || reading == 49) {    // END SESSION
    endSession();                      // end
  }

  licking();                           // determine if lick occured or was withdrawn
  frametimestamp();                    // store timestamps of frames

  if (ts >= nextcue && ((ITIflag && intervaldistribution < 3) || intervaldistribution > 2) && nextcue != 0) {
    if (secondcue == 0) {
      if (CSsignal[cueList[CSct]] == 1) {
        Serial.print(15 + cueList[CSct]);         // code data as CS1, CS2 or CS3 timestamp
        Serial.print(" ");
        Serial.print(ts);                         // send timestamp of cue
        Serial.print(" ");
        Serial.print(0);
        Serial.print('\n');
        cues();
      }
      else if (CSsignal[cueList[CSct]] == 2) {
        Serial.print(21 + cueList[CSct]);
        Serial.print(" ");
        Serial.print(ts);                         // send timestamp of light cue
        Serial.print(" ");
        Serial.print(0);                          // indicates second cue
        Serial.print('\n');
        lights();
      }
      if (CSsecondcue[cueList[CSct]] != 0) {
        nextcue = ts + delayforsecondcue[cueList[CSct]];
        secondcue = 1;
      }
      else {
        cueover = true;
        nextcue = 0;
      }

      if (intervaldistribution < 3) {
        nextfxdsolenoid = ts + CS_t_fxd[2 * cueList[CSct]];    // next fixed solenoid comes at a fixed delay following cue onset
        numfxdsolenoids = 0;
      }
      else if (intervaldistribution == 3) {
        fxdrwtime[CSct] = ts + CS_t_fxd[2 * cueList[CSct] + 1];
        if (nextfxdsolenoid == 0) {
          nextfxdsolenoid = fxdrwtime[fxdrwct];
        }
      }
    }
    else if (secondcue == 1) {
      if (CSsecondcue[cueList[CSct]] == 1) {               // if second cue is sound cue, deliver sound
        Serial.print(15 + cueList[CSct]);
        Serial.print(" ");
        Serial.print(ts);                         // send timestamp of sound cue
        Serial.print(" ");
        Serial.print(1);                          // indicates second cue
        Serial.print('\n');
        cues();
      }
      else if (CSsecondcue[cueList[CSct]] == 2) {          // if second cue is light cue, deliver light
        Serial.print(21 + cueList[CSct]);
        Serial.print(" ");
        Serial.print(ts);                         // send timestamp of light cue
        Serial.print(" ");
        Serial.print(1);                          // indicates second cue
        Serial.print('\n');
        lights();
      }
      secondcue = 0;
      nextcue = 0;
      cueover = true;
    }

    if (CSlasercheck[cueList[CSct]]) {
      deliverlasertocues();              // check whether to and deliver laser if needed
    }

    if (intervaldistribution > 2 && cueover) {
      CSct++;
      if (intervaldistribution < 5) {
        if (CSct >= totalnumtrials && intervaldistribution > 3) {
          nextfxdsolenoid = 0;
          nextcue = 0;
          sessionendtime = ts + 5000;
        }
        u = random(0, 10000);
        temp = (float)u / 10000;
        temp1 = (float)truncITI / meanITI;
        temp1 = exp(-temp1);
        temp1 = 1 - temp1;
        temp = temp * temp1;
        temp = -log(1 - temp);
        nextcue =  (unsigned long)ts + meanITI * temp;
      }
      else {
        if (CSct > totalnumtrials) {
          nextcue = 0;
          nextfxdsolenoid = 0;
          sessionendtime = ts + 5000;
        }
        else {
          if (CSct < fxdrwct) {
            nextcue = cuetime[CSct];
          }
          else {
            nextcue = 0;
          }
        }
      }
    }
    else if (cueover) {
      ITIflag = false;
      cueover = false;
    }
  }

  // UNCOMMENT THESE LINES FOR TRIGGERING COLLECTION TRIAL-BY-TRIAL

  //    if (ts >= nextttlouton && nextttlouton != 0) {
  //      digitalWrite(ttloutpin, HIGH);
  //      nextttloutoff = ts + ttloutdur;
  //      nextttlouton = 0;
  //    }
  //
  //    if (ts >= nextttloutoff && nextttloutoff != 0) {
  //      digitalWrite(ttloutpin, LOW);
  //      nextttloutoff = 0;
  //    }

  // TILL HERE

  // Pulse cue
  if (ts >= cuePulseOff && cuePulseOff != 0 && ts < cueOff) {
    noTone(speaker1);                   // turn off tone
    noTone(speaker2);
    if (CSincrease[cueList[CSct]] == 0) {
      cuePulseOn = ts + 200;
    }
    else {
      cuePulseOn = ts + 5;
    }
    cuePulseOff = 0;
  }

  if (ts >= cuePulseOn && cuePulseOn != 0 && ts < cueOff && CSincrease[cueList[CSct]] == 0) {
    tone(CSspeaker[cueList[CSct]], CSfreq[cueList[CSct]]);               // turn on tone
    cuePulseOff = ts + 200;                  // Cue pulsing
    cuePulseOn = 0;                          // No cue pulsing
  }

  // Increasing cue
  if (ts >= cuePulseOn && cuePulseOn != 0 && ts < cueOff && CSincrease[cueList[CSct]] == 1) {
    if (CSfreq[cueList[CSct]] + tempincrease < 7000) {
      tone(speaker2, CSfreq[cueList[CSct]] + tempincrease);             // turn on tone
    }
    else {
      tone(speaker1, CSfreq[cueList[CSct]] - tempincrease);             // turn on tone
    }
    tempincrease = tempincrease + 80;
    cuePulseOff = ts + 200;                  // Cue pulsing
    cuePulseOn = 0;                          // No cue pulsing
  }


  // Pulse LASER
  if (ts >= nextlaser && nextlaser != 0) {
    Serial.print(31);                        // code data as laser timestamp
    Serial.print(" ");
    Serial.print(ts);                        // send timestamp of laser
    Serial.print(" ");
    Serial.print(0);
    Serial.print('\n');
    digitalWrite(laser, HIGH);
    laserPulseOff = ts + laserpulseperiod;
    laserOff = ts + laserduration;
    nextlaser = 0;
  }

  if (ts >= laserPulseOff && laserPulseOff != 0 && ts < laserOff) {
    digitalWrite(laser, LOW);                   // turn off laser
    laserPulseOn = ts + laserpulseoffperiod;
    laserPulseOff = 0;
  }

  if (ts >= laserPulseOn && laserPulseOn != 0 && ts < laserOff) {
    digitalWrite(laser, HIGH);                   // turn on laser
    laserPulseOn = 0;
    laserPulseOff = ts + laserpulseperiod;
  }

  // Turn off cue
  if (ts >= cueOff && cueOff != 0) {   // CUE CESSATION
    noTone(speaker1);                   // turn off cue
    noTone(speaker2);
    cueOff = 0;
    cuePulseOff = 0;
    cuePulseOn = 0;
    tempincrease = 0;
    // Sync with fiber photometry
    digitalWrite(ttloutstoppin, LOW);
  }
  // Turn off laser
  if (ts >= laserOff && laserOff != 0) {   // LASER CESSATION
    digitalWrite(laser, LOW);              // turn off laser
    laserOff = 0;
  }
  // Turn off light
  if (ts >= lightOff && lightOff != 0) {    // LIGHT CESSATION
    digitalWrite(light1, LOW);              // turn off light
    digitalWrite(light2, LOW);
    lightOff = 0;
  }

  if (((!ITIflag && intervaldistribution < 3) || intervaldistribution > 2) && ts >= nextfxdsolenoid && nextfxdsolenoid != 0) { // give fixed solenoid
    if (intervaldistribution < 3) {
      Serial.print(CSsolenoidcode[2 * cueList[CSct] + numfxdsolenoids]);
    }
    else if (intervaldistribution > 2) {
      Serial.print(CSsolenoidcode[2 * cueList[fxdrwct] + 1]);
    }
    Serial.print(" ");
    Serial.print(ts);                      //   send timestamp of solenoid onset
    Serial.print(" ");
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

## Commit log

2023-02-09 fix errors in the circuit diagram
2023-02-09 update resistor info
2023-05-25 update programmatic GUI and corresponding arduino files
